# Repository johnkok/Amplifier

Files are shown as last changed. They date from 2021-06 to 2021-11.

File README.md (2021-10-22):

# Amplifier
This is an amplifier project, inluding both software sources for CPU/DSP and also hardware design files.

# folders
**fw:** includes the ST32F407 CPU firmware<br />
**DSP:** includes the ADAU1497 design files<br />
**amp_board:** includes the kicad design foles for the audio power amplifier board<br />
**cntrl_board:** includes the controller board kicad design files<br />
**3d:** 3d printer freecad files<br />

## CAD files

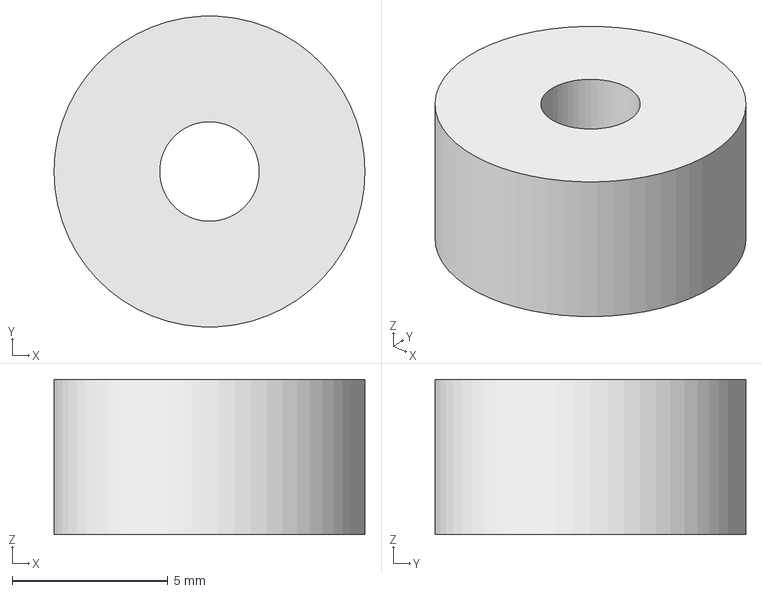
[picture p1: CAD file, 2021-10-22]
3d/spacer.FCStd
10.0 x 9.99 x 5.00 mm

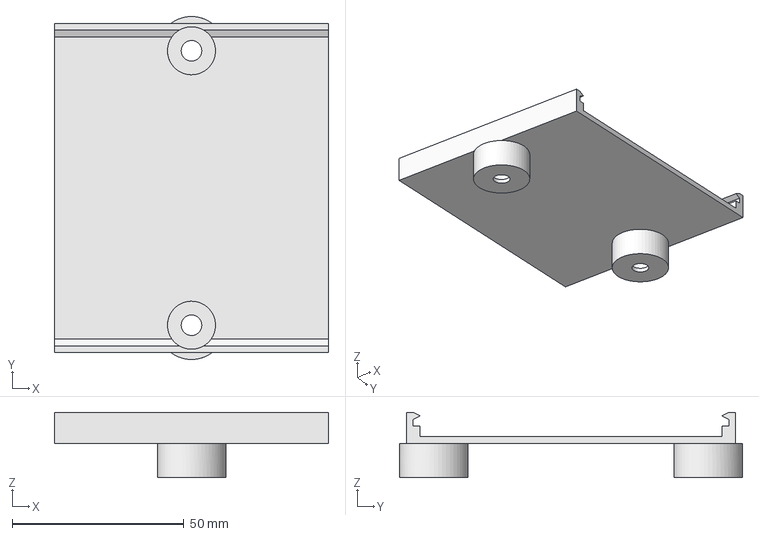
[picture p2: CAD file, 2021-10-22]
3d/holder.FCStd
80.0 x 100.0 x 19.0 mm

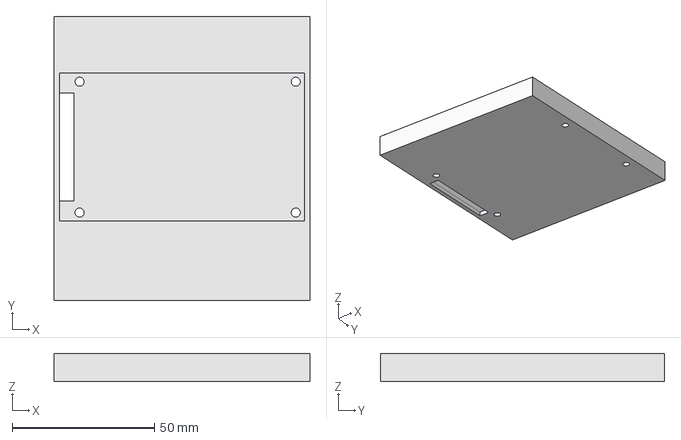
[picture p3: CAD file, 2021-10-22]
3d/lcd_frame.FCStd
90.0 x 100.0 x 10.0 mm

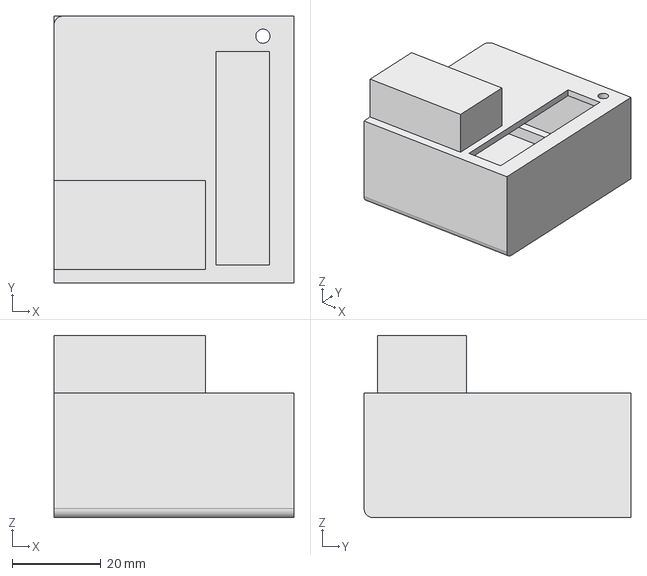
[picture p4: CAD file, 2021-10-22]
3d/fuse.FCStd
54.0 x 60.0 x 41.0 mm

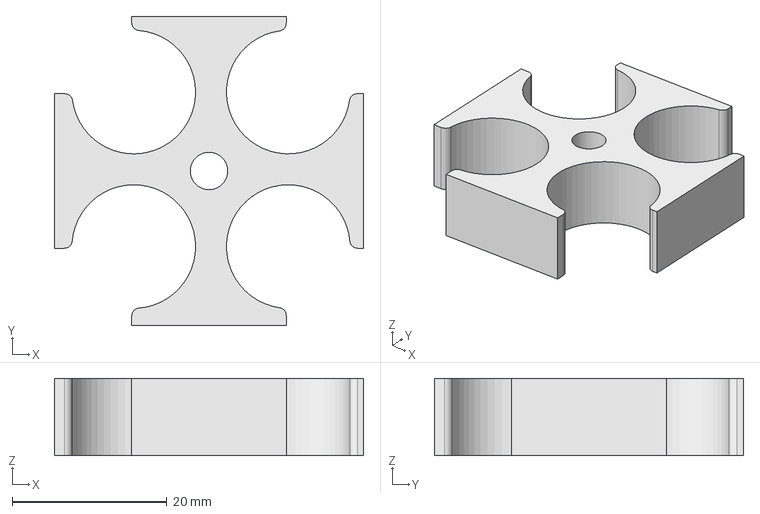
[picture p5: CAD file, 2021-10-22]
3d/cable_spacer.FCStd
40.0 x 40.0 x 10.0 mm

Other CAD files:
3d/cable_spacer.stl
3d/fuse.stl
3d/holder.stl
3d/lcd_frame.stl
3d/spacer.stl

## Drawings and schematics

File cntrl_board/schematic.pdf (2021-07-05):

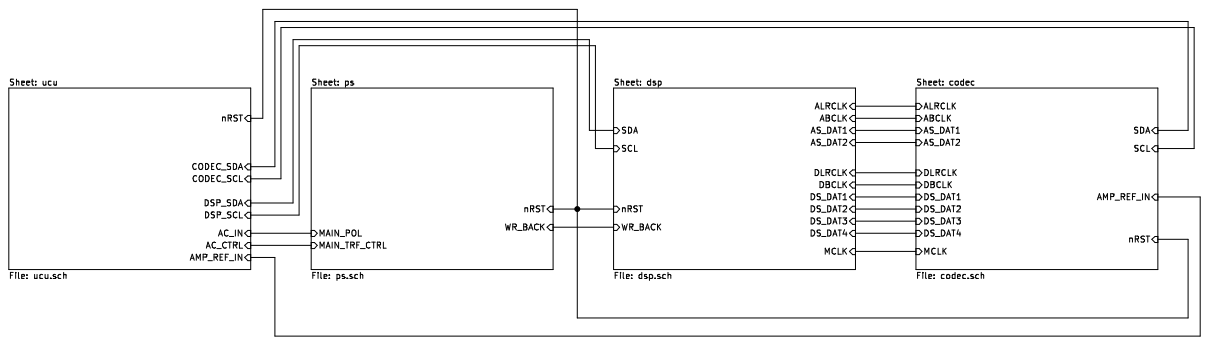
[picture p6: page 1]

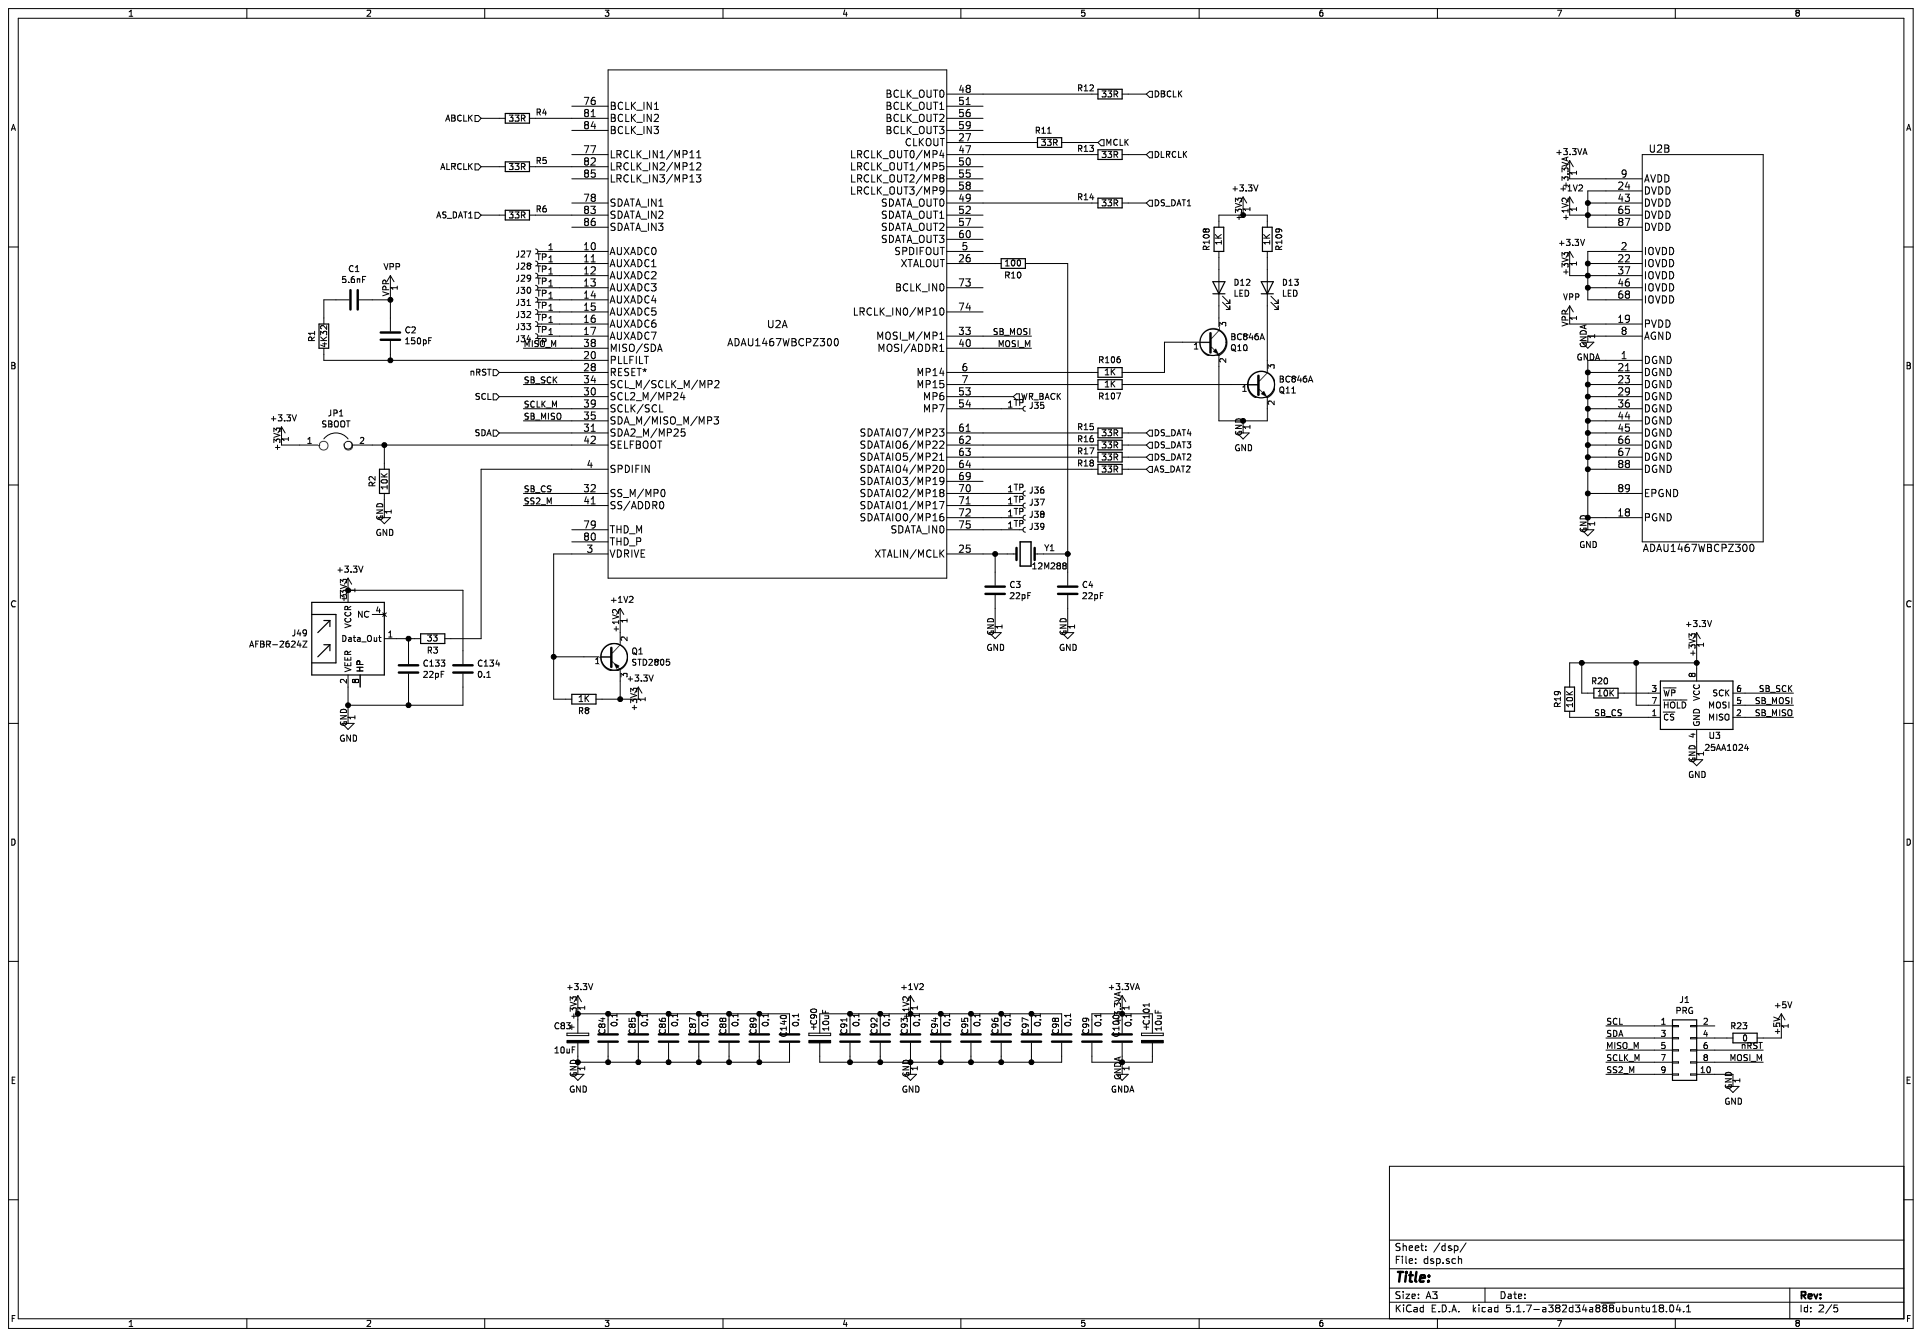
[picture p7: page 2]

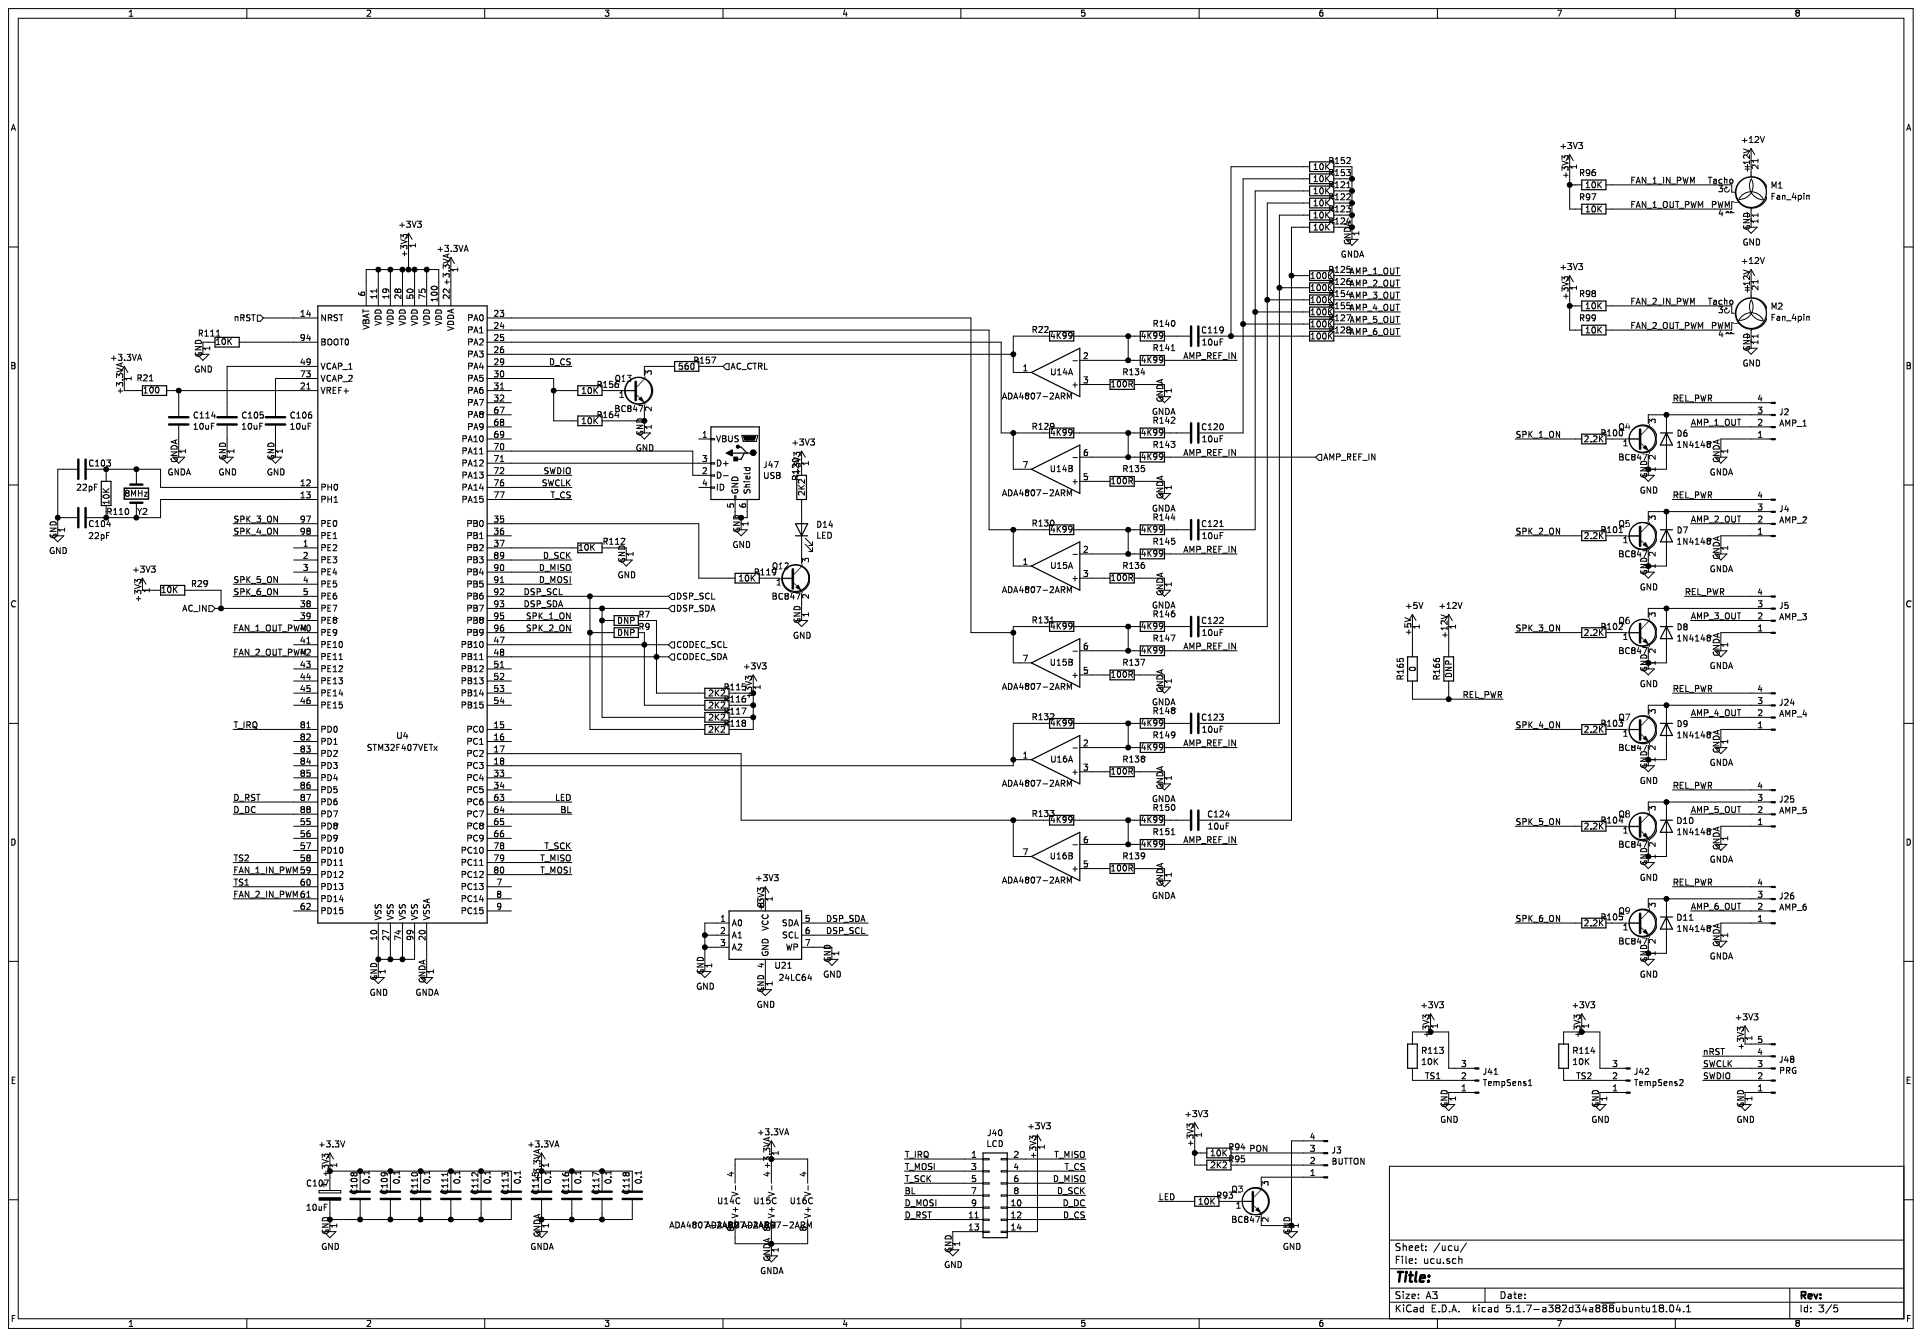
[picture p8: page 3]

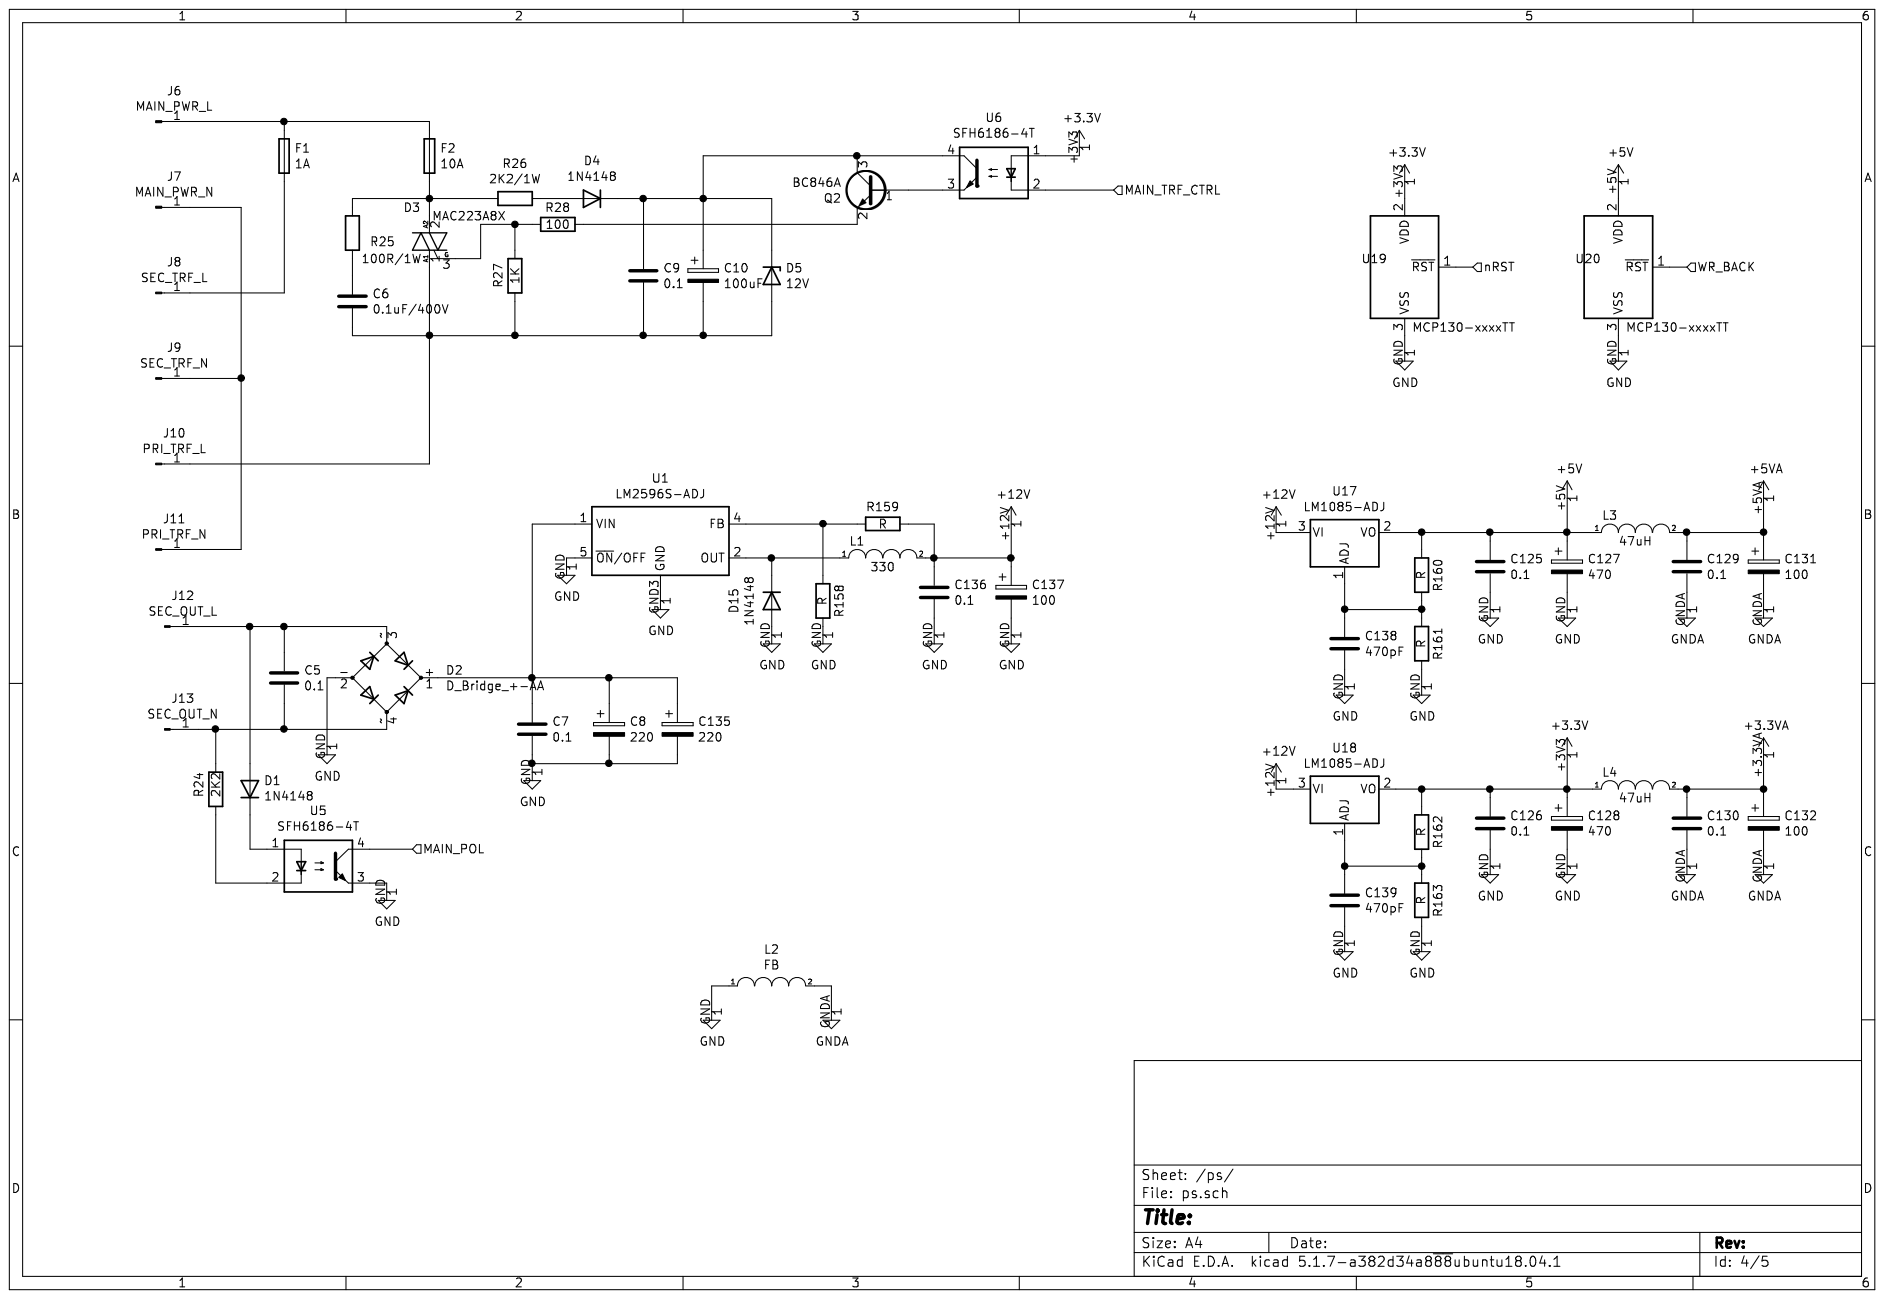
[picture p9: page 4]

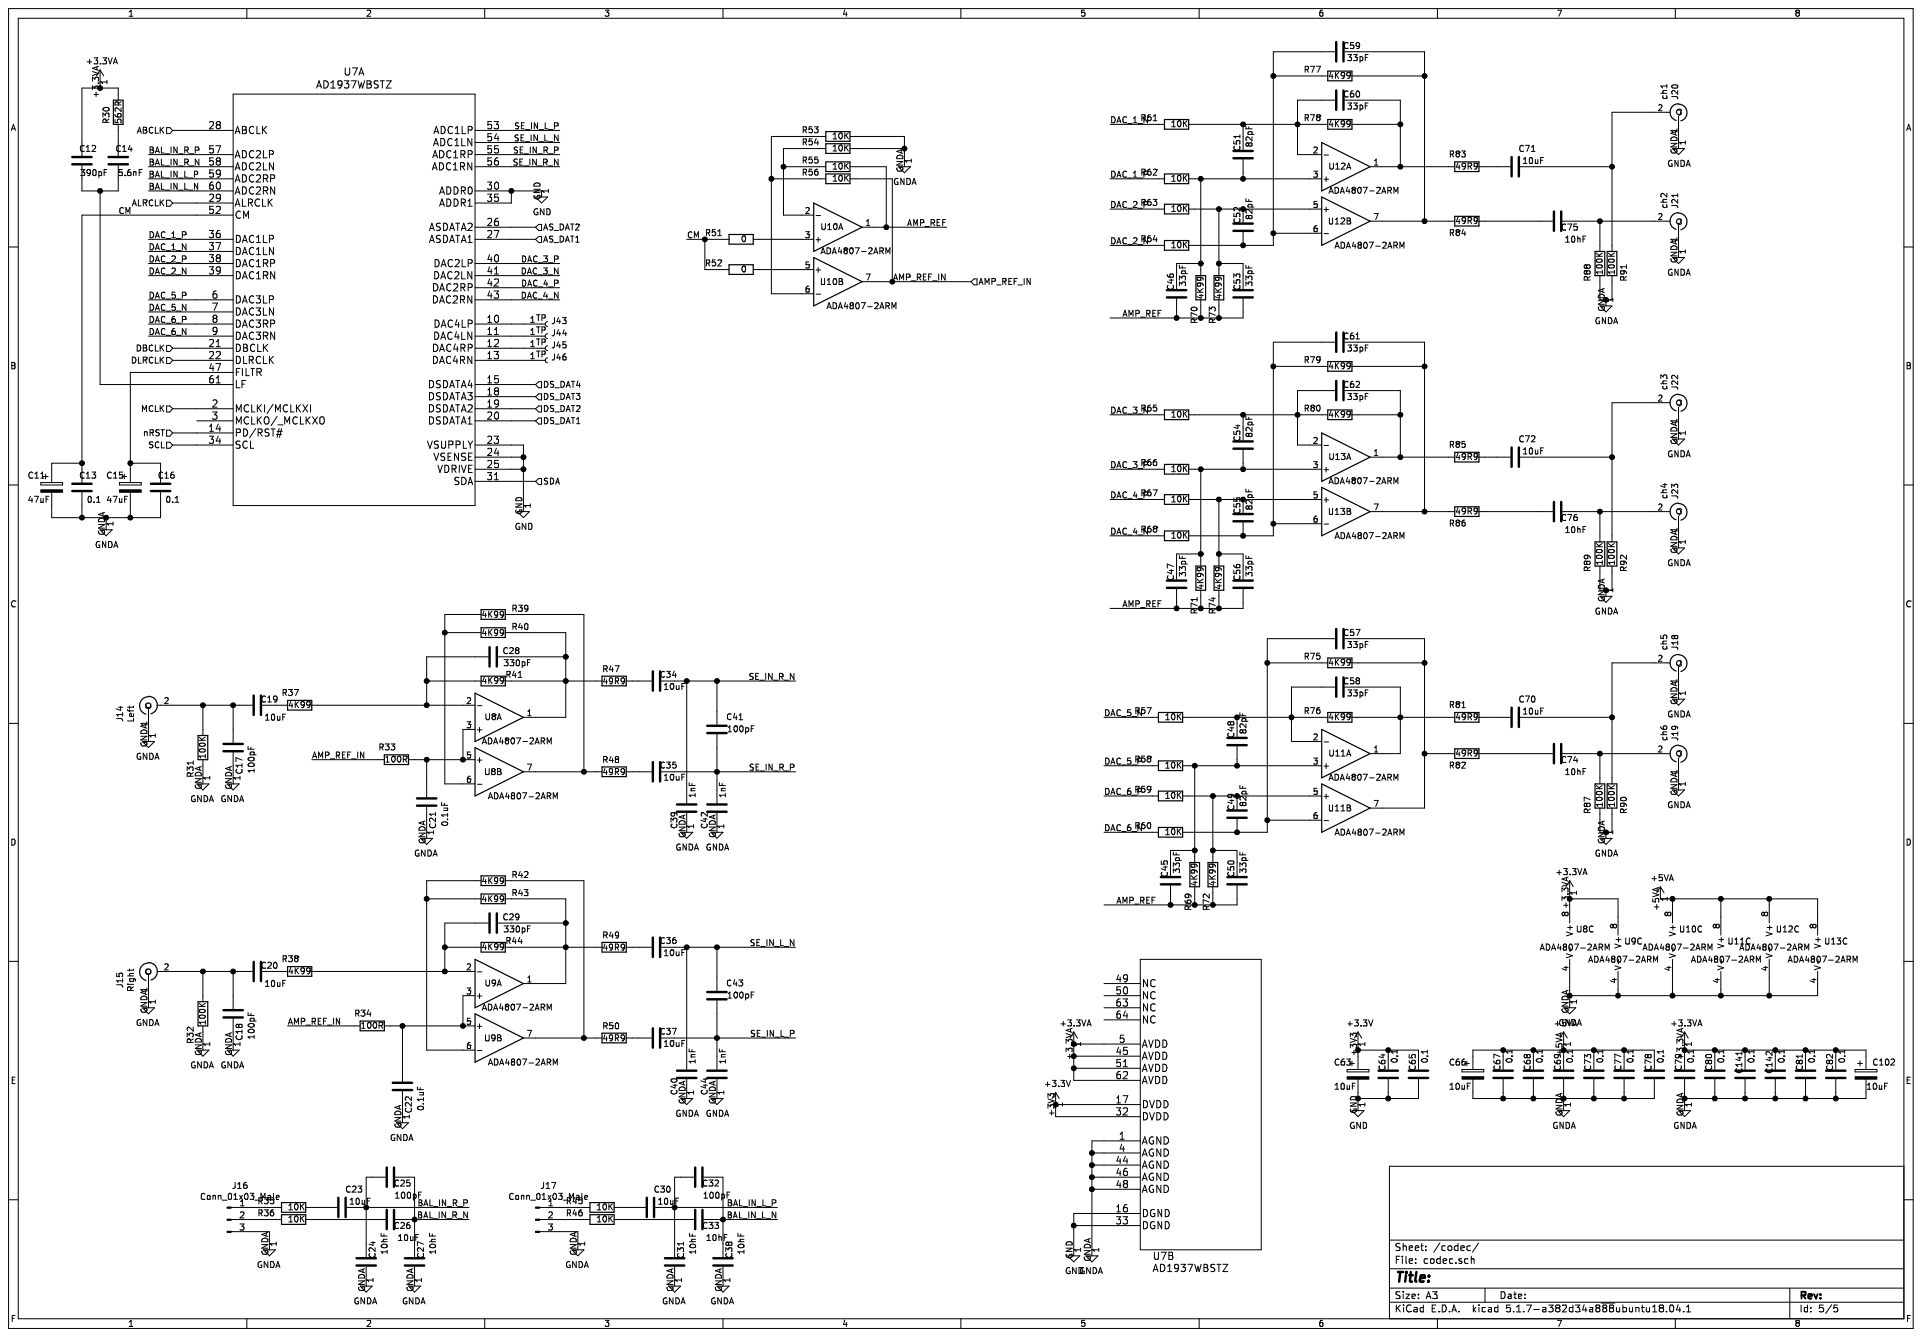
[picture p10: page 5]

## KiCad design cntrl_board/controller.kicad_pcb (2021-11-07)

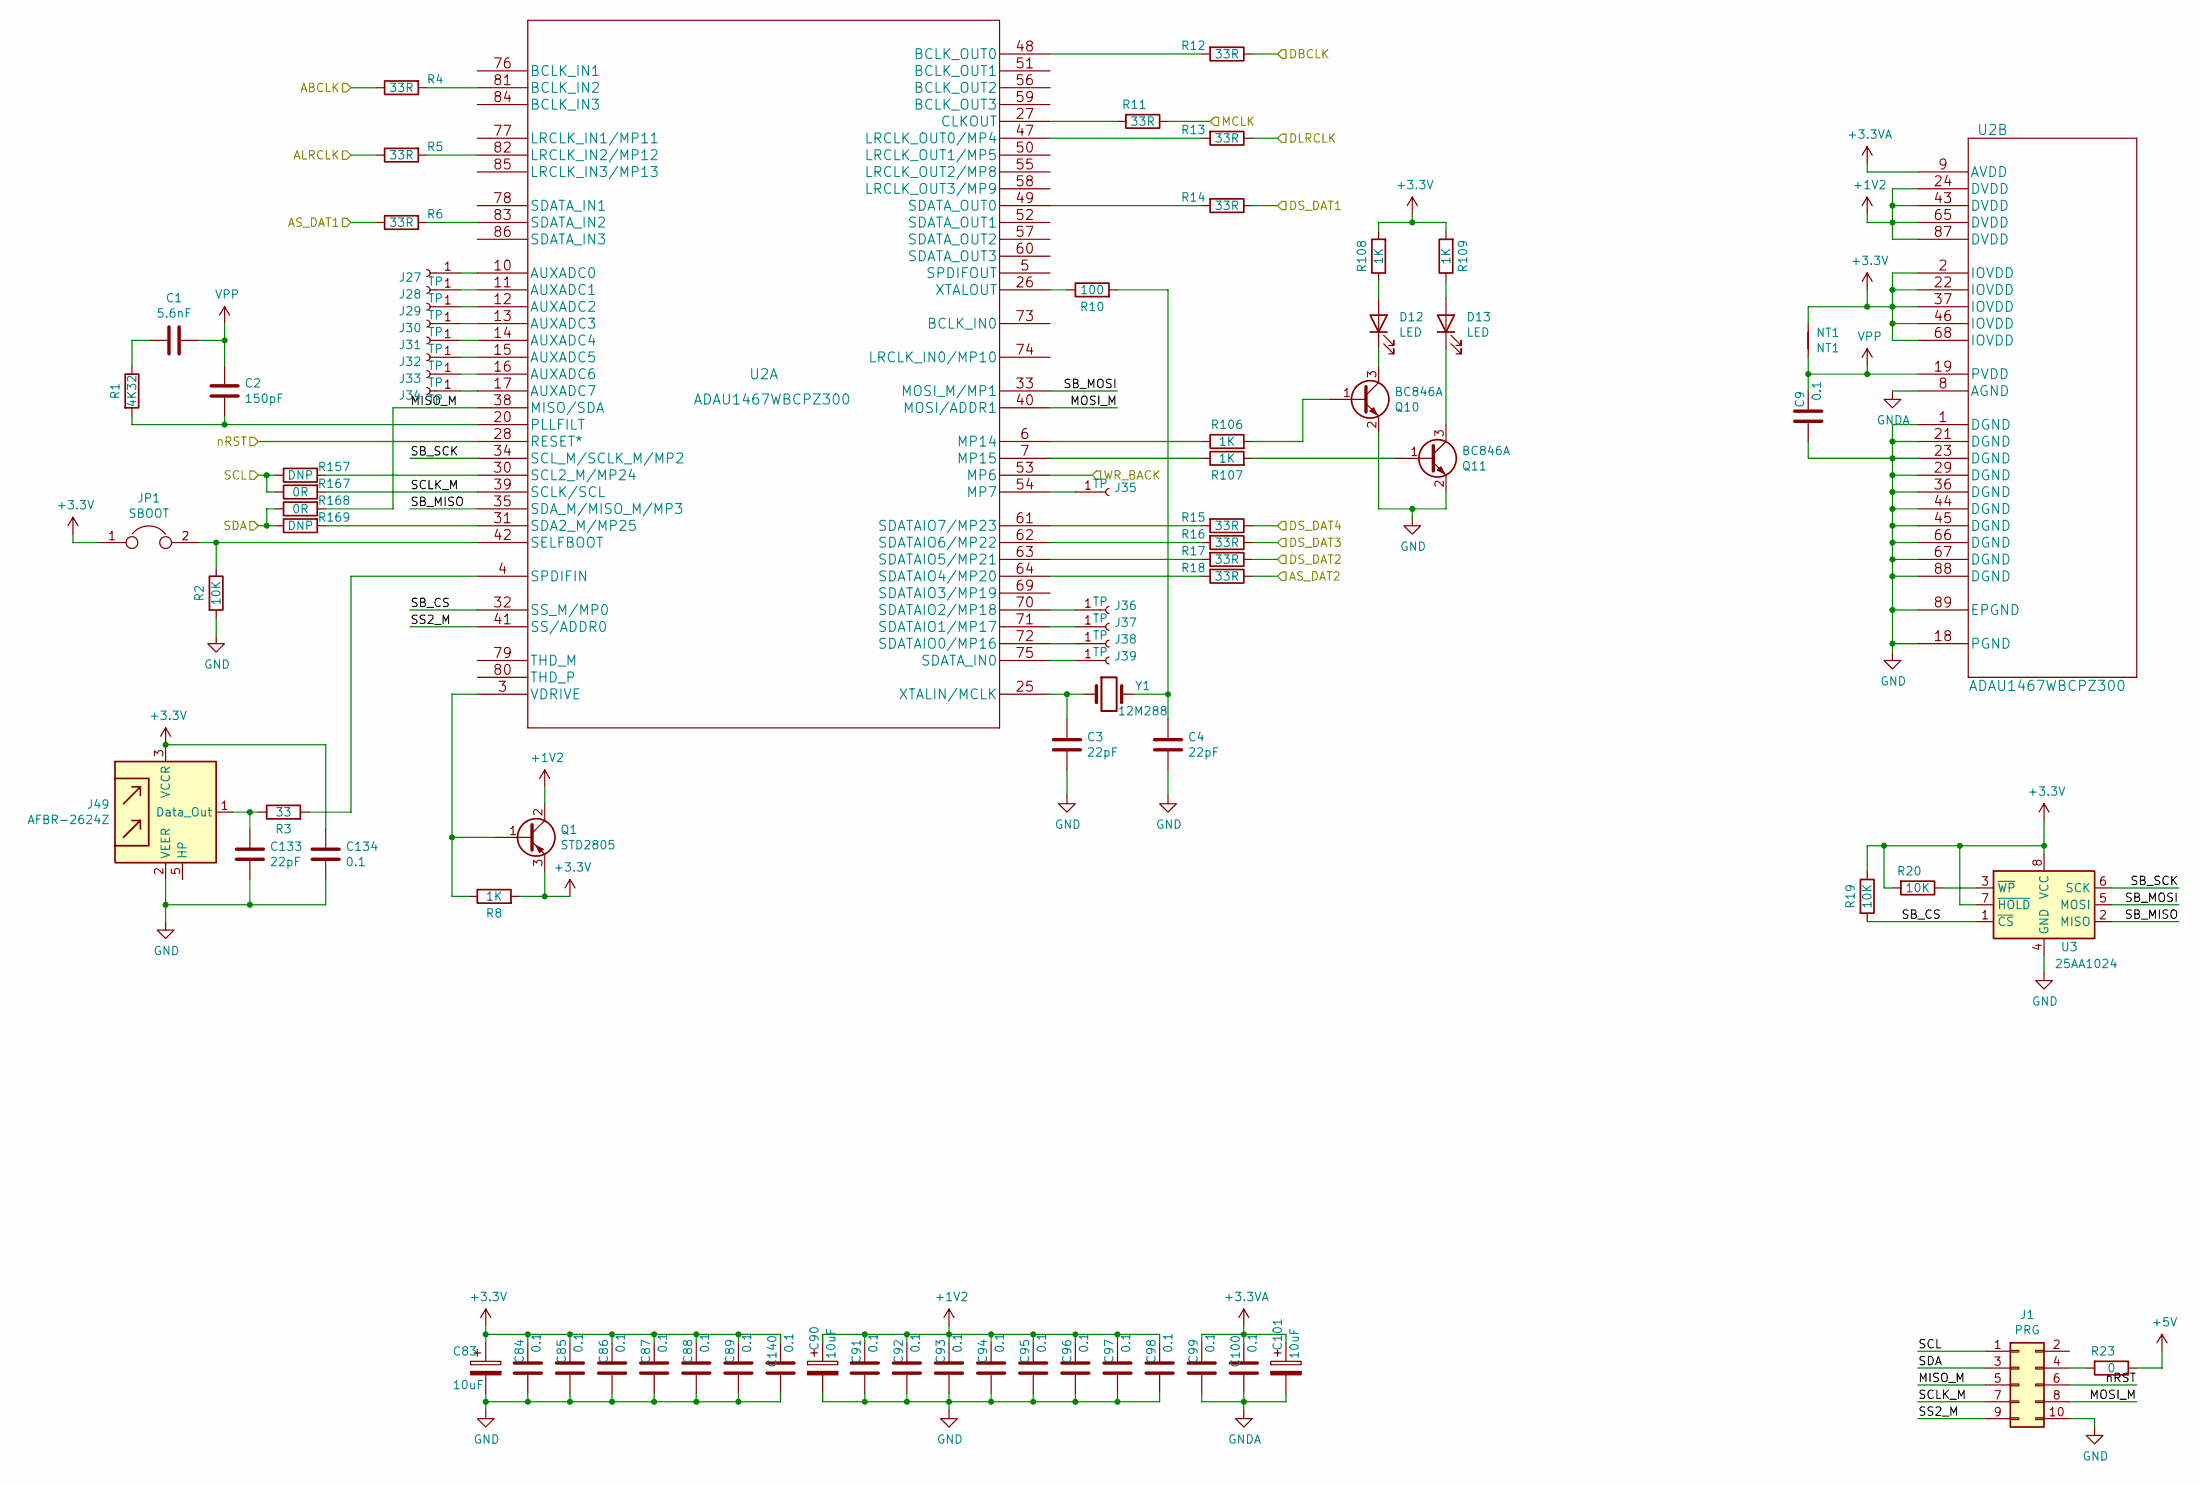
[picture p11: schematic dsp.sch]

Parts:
C1: 5.6nF; C_0603_1608Metric_Pad1.08x0.95mm_HandSolder
C2: 150pF; C_0603_1608Metric_Pad1.08x0.95mm_HandSolder
C3, C4, C133: 22pF; C_0603_1608Metric_Pad1.08x0.95mm_HandSolder
C9, C84, C85, C86, C87, C88, C89, C91, C92, C93, C94, C95, C96, C97, C98, C99, C100, C134, C140: 0.1; C_0603_1608Metric_Pad1.08x0.95mm_HandSolder
C83, C90, C101: 10uF; CP_Elec_5x5.8
D12, D13: LED; LED_0603_1608Metric_Pad1.05x0.95mm_HandSolder
J1: PRG; IDC-Header_2x05_P2.54mm_Vertical
J27, J28, J29, J30, J31, J32, J33, J34, J35, J36, J37, J38, J39: TP; TestPoint_Keystone_5000-5004_Miniature
J49: AFBR-2624Z; TOSLINK
JP1: SBOOT; PinHeader_1x02_P2.54mm_Vertical
NT1: NT1; NetTie-2_SMD_Pad0.5mm
Q1: STD2805; TO-252-3_TabPin2
Q10, Q11: BC846A; SOT-23
R1: 4K32; R_0603_1608Metric_Pad0.98x0.95mm_HandSolder
R2, R19, R20: 10K; R_0603_1608Metric_Pad0.98x0.95mm_HandSolder
R3: 33; R_0603_1608Metric_Pad0.98x0.95mm_HandSolder
R4, R5, R6, R11, R12, R13, R14, R15, R16, R17, R18: 33R; R_0603_1608Metric_Pad0.98x0.95mm_HandSolder
R8, R106, R107, R108, R109: 1K; R_0603_1608Metric_Pad0.98x0.95mm_HandSolder
R10: 100; R_0603_1608Metric_Pad0.98x0.95mm_HandSolder
R23: 0; R_0603_1608Metric_Pad0.98x0.95mm_HandSolder
R157, R169: DNP; R_0603_1608Metric_Pad0.98x0.95mm_HandSolder
R167, R168: 0R; R_0603_1608Metric_Pad0.98x0.95mm_HandSolder
U2: ADAU1467WBCPZ300
U3: 25AA1024; SOIJ-8_5.3x5.3mm_P1.27mm
Y1: 12M288; Crystal_HC49-U_Vertical

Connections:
+1V2: C90.1, C91.1, C92.1, C93.1, C94.1, C95.1, C96.1, C97.1, C98.1, Q1.2 (C), U2.24 (DVDD), U2.43 (DVDD), U2.65 (DVDD), U2.87 (DVDD)
+3.3VA: C99.1, C100.1, C101.1, U2.9 (AVDD); also elsewhere on the board
+5V: R23.1; also elsewhere on the board
/codec/ABCLK: R4.1; also elsewhere on the board
/codec/ALRCLK: R5.1; also elsewhere on the board
/codec/AS_DAT1: R6.1; also elsewhere on the board
/codec/AS_DAT2: R18.1; also elsewhere on the board
/codec/DBCLK: R12.1; also elsewhere on the board
/codec/DLRCLK: R13.1; also elsewhere on the board
/codec/DS_DAT1: R14.1; also elsewhere on the board
/codec/DS_DAT2: R17.1; also elsewhere on the board
/codec/DS_DAT3: R16.1; also elsewhere on the board
/codec/DS_DAT4: R15.1; also elsewhere on the board
/codec/MCLK: R11.1; also elsewhere on the board
/codec/nRST: J1.6, U2.28 (RESET*); also elsewhere on the board
/dsp/MISO_M: J1.5, R168.2, U2.38 (MISO/SDA)
/dsp/MOSI_M: J1.8, U2.40 (MOSI/ADDR1)
/dsp/SB_CS: R19.2, U2.32 (SS_M/MP0), U3.1 (~CS)
/dsp/SB_MISO: U2.35 (SDA_M/MISO_M/MP3), U3.2 (MISO)
/dsp/SB_MOSI: U2.33 (MOSI_M/MP1), U3.5 (MOSI)
/dsp/SB_SCK: U2.34 (SCL_M/SCLK_M/MP2), U3.6 (SCK)
/dsp/SCLK_M: J1.7, R167.2, U2.39 (SCLK/SCL)
/dsp/SS2_M: J1.9, U2.41 (SS/ADDR0)
/dsp/WR_BACK: U2.53 (MP6); also elsewhere on the board
/ucu/DSP_SCL: J1.1, R157.1, R167.1; also elsewhere on the board
/ucu/DSP_SDA: J1.3, R168.1, R169.1; also elsewhere on the board
GND: C3.2, C4.2, C9.2, C83.2, C84.2, C85.2, C86.2, C87.2, C88.2, C89.2, C90.2, C91.2, C92.2, C93.2, C94.2, C95.2, C96.2, C97.2, C98.2, C133.2, C134.2, C140.2, J1.10, J49.2 (VEER), Q10.2 (E), Q11.2 (E), R2.2, U2.1 (DGND), U2.18 (PGND), U2.21 (DGND), U2.23 (DGND), U2.29 (DGND), U2.36 (DGND), U2.44 (DGND), U2.45 (DGND), U2.66 (DGND), U2.67 (DGND), U2.88 (DGND), U2.89 (EPGND), U3.4 (GND); also elsewhere on the board
GNDA: C99.2, C100.2, C101.2, U2.8 (AGND); also elsewhere on the board
unnamed: C1.1, R1.1
unnamed: C2.1, R1.2, U2.20 (PLLFILT)
unnamed: C3.1, U2.25 (XTALIN/MCLK), Y1.1
unnamed: C4.1, R10.2, Y1.2
unnamed: C133.1, J49.1 (Data_Out), R3.1
unnamed: D12.1 (K), Q10.3 (C)
unnamed: D12.2 (A), R108.1
unnamed: D13.1 (K), Q11.3 (C)
unnamed: D13.2 (A), R109.1
unnamed: J1.4, R23.2
unnamed: J27.1, U2.10 (AUXADC0)
unnamed: J28.1, U2.11 (AUXADC1)
unnamed: J29.1, U2.12 (AUXADC2)
unnamed: J30.1, U2.13 (AUXADC3)
unnamed: J31.1, U2.14 (AUXADC4)
unnamed: J32.1, U2.15 (AUXADC5)
unnamed: J33.1, U2.16 (AUXADC6)
unnamed: J34.1, U2.17 (AUXADC7)
unnamed: J35.1, U2.54 (MP7)
unnamed: J36.1, U2.70 (SDATAIO2/MP18)
unnamed: J37.1, U2.71 (SDATAIO1/MP17)
unnamed: J38.1, U2.72 (SDATAIO0/MP16)
unnamed: J39.1, U2.75 (SDATA_IN0)
unnamed: JP1.2, R2.1, U2.42 (SELFBOOT)
unnamed: Q1.1 (B), R8.1, U2.3 (VDRIVE)
unnamed: Q10.1 (B), R106.2
unnamed: Q11.1 (B), R107.2
unnamed: R3.2, U2.4 (SPDIFIN)
unnamed: R4.2, U2.81 (BCLK_IN2)
unnamed: R5.2, U2.82 (LRCLK_IN2/MP12)
unnamed: R6.2, U2.83 (SDATA_IN2)
unnamed: R10.1, U2.26 (XTALOUT)
unnamed: R11.2, U2.27 (CLKOUT)
unnamed: R12.2, U2.48 (BCLK_OUT0)
unnamed: R13.2, U2.47 (LRCLK_OUT0/MP4)
unnamed: R14.2, U2.49 (SDATA_OUT0)
unnamed: R15.2, U2.61 (SDATAIO7/MP23)
unnamed: R16.2, U2.62 (SDATAIO6/MP22)
unnamed: R17.2, U2.63 (SDATAIO5/MP21)
unnamed: R18.2, U2.64 (SDATAIO4/MP20)
unnamed: R20.1, U3.3 (~WP)
unnamed: R106.1, U2.6 (MP14)
unnamed: R107.1, U2.7 (MP15)
unnamed: R157.2, U2.30 (SCL2_M/MP24)
unnamed: R169.2, U2.31 (SDA2_M/MP25)
VPP: C1.2, C2.2, C9.1, NT1.1, U2.19 (PVDD)

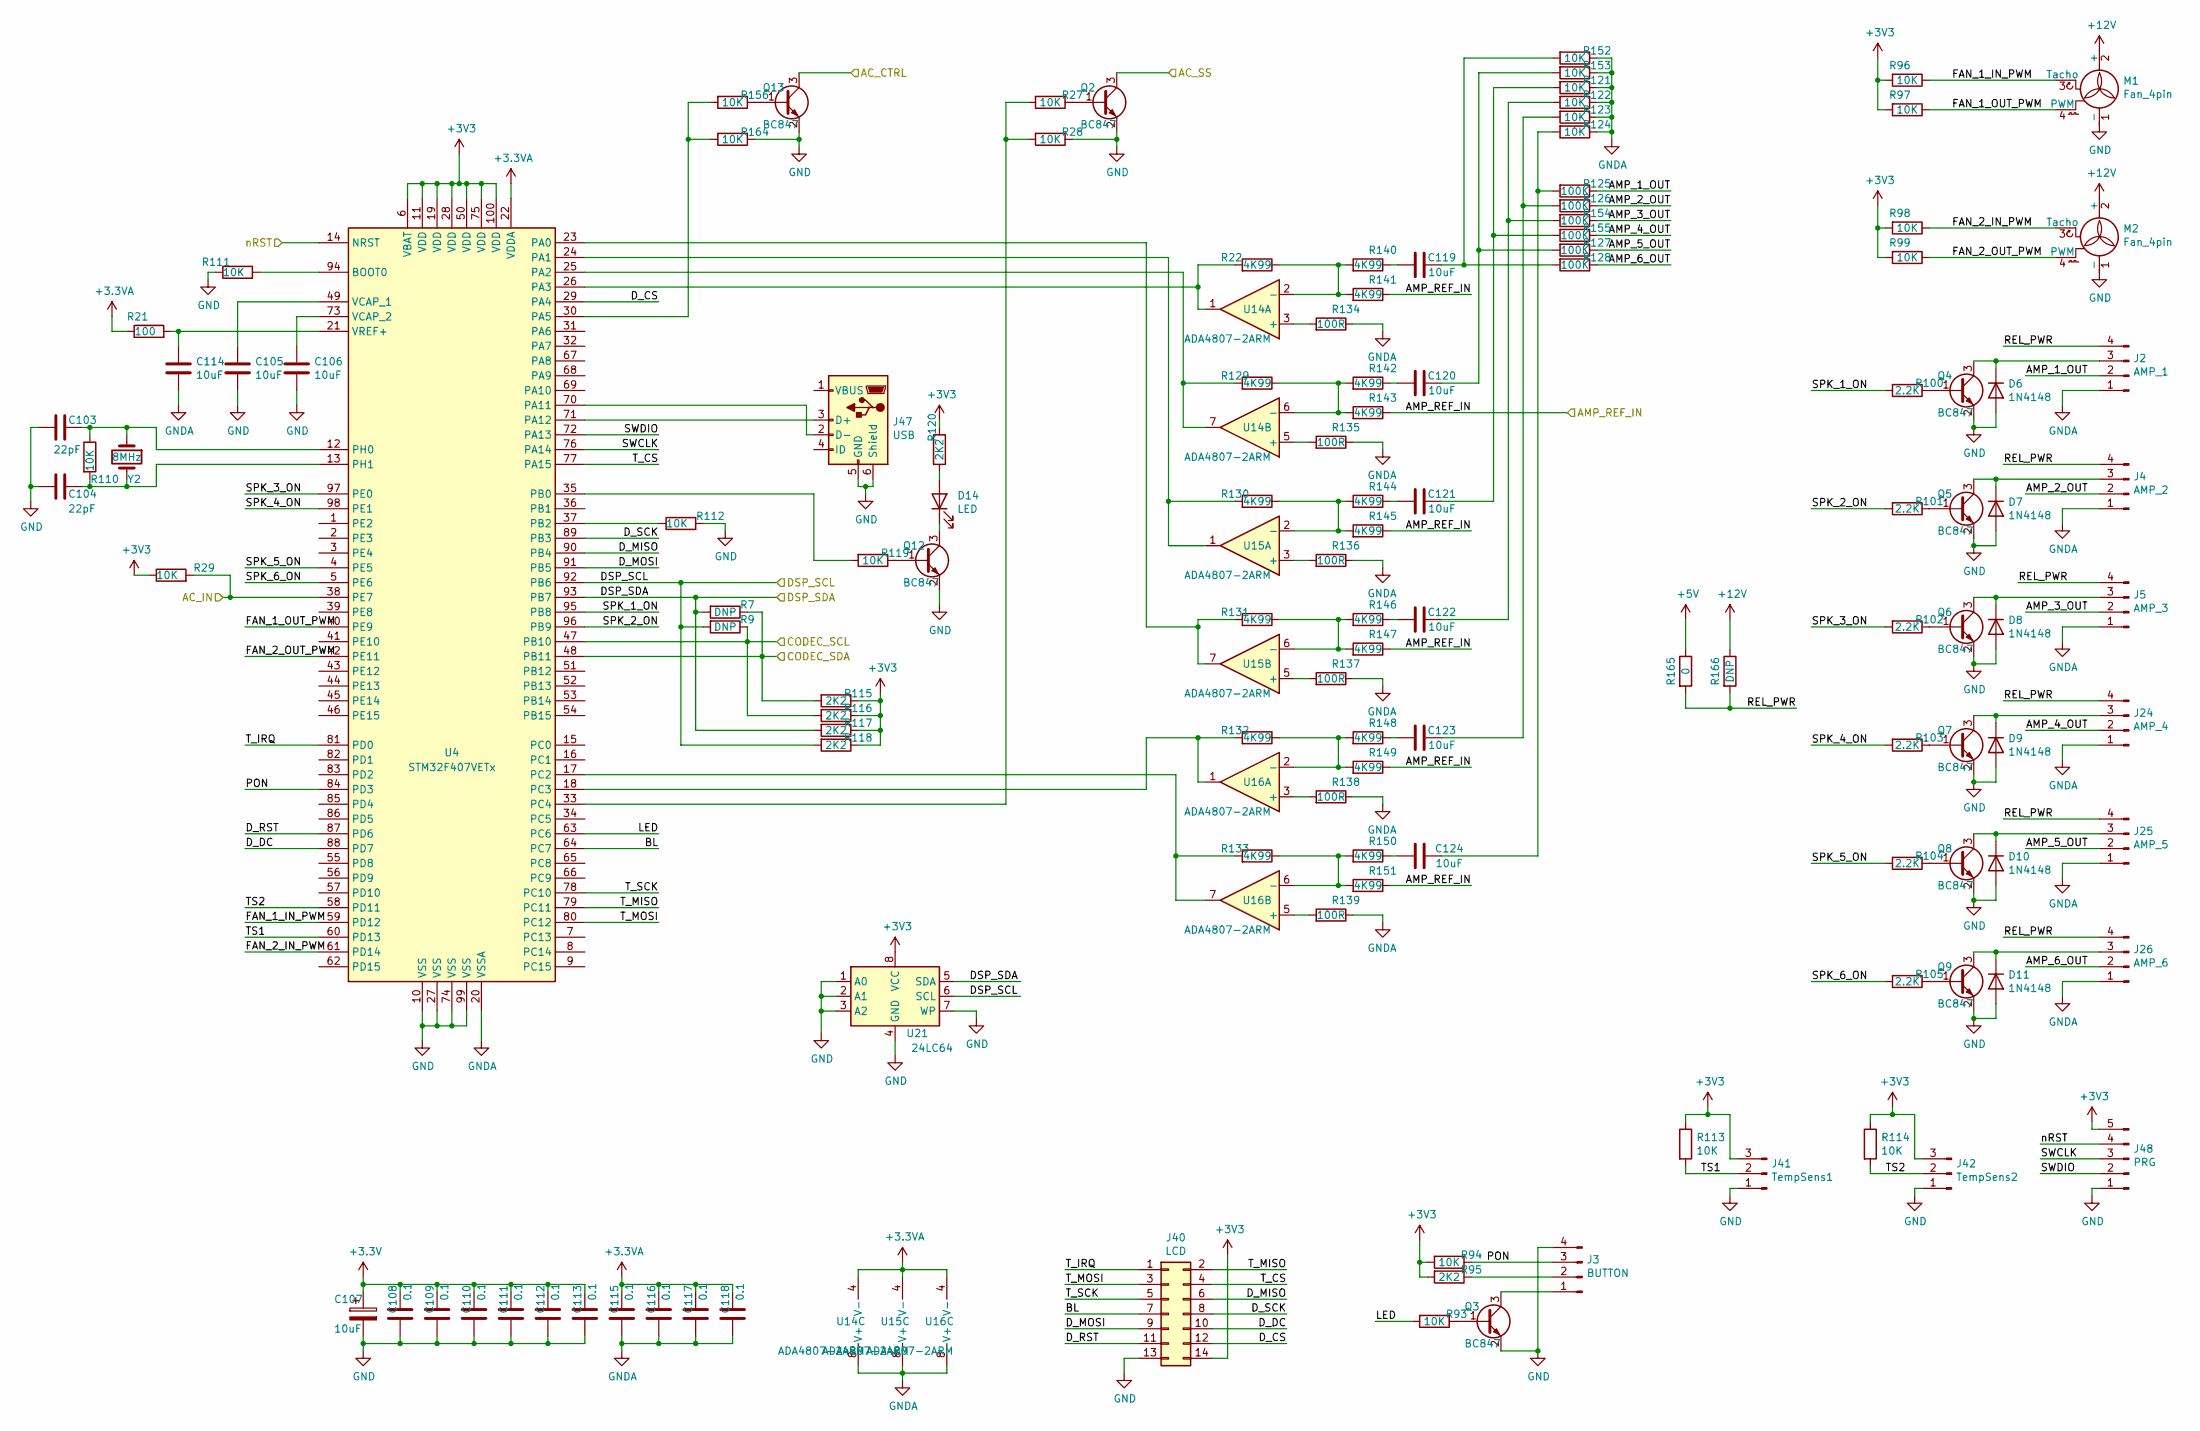
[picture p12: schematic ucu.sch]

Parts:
C103, C104: 22pF; R_0603_1608Metric_Pad0.98x0.95mm_HandSolder
C105, C106, C114, C119, C120, C121, C122, C123, C124: 10uF; C_0805_2012Metric_Pad1.18x1.45mm_HandSolder
C107: 10uF; CP_Elec_5x5.8
C108, C109, C110, C111, C112, C113, C115, C116, C117, C118: 0.1; C_0603_1608Metric_Pad1.08x0.95mm_HandSolder
D6, D7, D8, D9, D10, D11: 1N4148; D_SOD-323_HandSoldering
D14: LED; LED_0603_1608Metric_Pad1.05x0.95mm_HandSolder
J2: AMP_1; PinHeader_1x04_P1.27mm_Vertical
J3: BUTTON; PinHeader_1x04_P2.54mm_Vertical
J4: AMP_2; PinHeader_1x04_P1.27mm_Vertical
J5: AMP_3; PinHeader_1x04_P1.27mm_Vertical
J24: AMP_4; PinHeader_1x04_P1.27mm_Vertical
J25: AMP_5; PinHeader_1x04_P1.27mm_Vertical
J26: AMP_6; PinHeader_1x04_P1.27mm_Vertical
J40: LCD; PinSocket_2x07_P2.54mm_Vertical
J41: TempSens1; PinHeader_1x03_P2.54mm_Vertical
J42: TempSens2; PinHeader_1x03_P2.54mm_Vertical
J47: USB; USB_Micro-B_Molex-105017-0001
J48: PRG; PinSocket_1x05_P2.54mm_Vertical
M1, M2: Fan_4pin; PinHeader_1x04_P2.54mm_Vertical
Q2, Q3, Q4, Q5, Q6, Q7, Q8, Q9, Q12, Q13: BC847; SOT-23
R7, R9: DNP; R_0603_1608Metric_Pad0.98x0.95mm_HandSolder
R21: 100; R_0603_1608Metric_Pad0.98x0.95mm_HandSolder
R22, R129, R130, R131, R132, R133, R140, R141, R142, R143, R144, R145, R146, R147, R148, R149, R150, R151: 4K99; R_0603_1608Metric_Pad0.98x0.95mm_HandSolder
R27, R28, R29, R93, R94, R96, R97, R98, R99, R110, R111, R112, R113, R114, R119, R121, R122, R123, R124, R152, R153, R156, R164: 10K; R_0603_1608Metric_Pad0.98x0.95mm_HandSolder
R95, R115, R116, R117, R118, R120: 2K2; R_0603_1608Metric_Pad0.98x0.95mm_HandSolder
R100, R101, R102, R103, R104, R105: 2.2K; R_0603_1608Metric_Pad0.98x0.95mm_HandSolder
R125, R126, R127, R128, R154, R155: 100K; R_0603_1608Metric_Pad0.98x0.95mm_HandSolder
R134, R135, R136, R137, R138, R139: 100R; R_0603_1608Metric_Pad0.98x0.95mm_HandSolder
R165: 0; R_1206_3216Metric_Pad1.30x1.75mm_HandSolder
R166: DNP; R_1206_3216Metric_Pad1.30x1.75mm_HandSolder
U4: STM32F407VETx; LQFP-100_14x14mm_P0.5mm
U14, U15, U16: ADA4807-2ARM; MSOP-8_3x3mm_P0.65mm
U21: 24LC64; SO-8_3.9x4.9mm_P1.27mm
Y2: 8MHz; Crystal_HC49-4H_Vertical

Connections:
+3.3VA: C115.1, C116.1, C117.1, C118.1, R21.1, U4.22 (VDDA), U14.4 (V-), U15.4 (V-), U16.4 (V-); also elsewhere on the board
+5V: R165.1; also elsewhere on the board
+12V: M1.2 (+), M2.2 (+), R166.1; also elsewhere on the board
/codec/AMP_REF_IN: R141.1, R143.1, R145.1, R147.1, R149.1, R151.1; also elsewhere on the board
/codec/nRST: J48.4, U4.14 (NRST); also elsewhere on the board
/ucu/AC_CTRL: Q13.3 (C); also elsewhere on the board
/ucu/AC_IN: R29.2, U4.38 (PE7); also elsewhere on the board
/ucu/AC_SS: Q2.3 (C); also elsewhere on the board
/ucu/AMP_1_OUT: J2.2, R125.1
/ucu/AMP_2_OUT: J4.2, R126.1
/ucu/AMP_3_OUT: J5.2, R154.1
/ucu/AMP_4_OUT: J24.2, R155.1
/ucu/AMP_5_OUT: J25.2, R127.1
/ucu/AMP_6_OUT: J26.2, R128.1
/ucu/BL: J40.7, U4.64 (PC7)
/ucu/CODEC_SCL: R9.1, R116.2, U4.47 (PB10); also elsewhere on the board
/ucu/CODEC_SDA: R7.1, R115.2, U4.48 (PB11); also elsewhere on the board
/ucu/DSP_SCL: R9.2, R118.2, U4.92 (PB6), U21.6 (SCL); also elsewhere on the board
/ucu/DSP_SDA: R7.2, R117.2, U4.93 (PB7), U21.5 (SDA); also elsewhere on the board
/ucu/D_CS: J40.12, U4.29 (PA4)
/ucu/D_DC: J40.10, U4.88 (PD7)
/ucu/D_MISO: J40.6, U4.90 (PB4)
/ucu/D_MOSI: J40.9, U4.91 (PB5)
/ucu/D_RST: J40.11, U4.87 (PD6)
/ucu/D_SCK: J40.8, U4.89 (PB3)
/ucu/FAN_1_IN_PWM: M1.3 (Tacho), R96.1, U4.59 (PD12)
/ucu/FAN_1_OUT_PWM: M1.4 (PWM), R97.1, U4.40 (PE9)
/ucu/FAN_2_IN_PWM: M2.3 (Tacho), R98.1, U4.61 (PD14)
/ucu/FAN_2_OUT_PWM: M2.4 (PWM), R99.1, U4.42 (PE11)
/ucu/LED: R93.2, U4.63 (PC6)
/ucu/PON: J3.3, R94.1, U4.84 (PD3)
/ucu/REL_PWR: J2.4, J4.4, J5.4, J24.4, J25.4, J26.4, R165.2, R166.2
/ucu/SPK_1_ON: R100.2, U4.95 (PB8)
/ucu/SPK_2_ON: R101.2, U4.96 (PB9)
/ucu/SPK_3_ON: R102.2, U4.97 (PE0)
/ucu/SPK_4_ON: R103.2, U4.98 (PE1)
/ucu/SPK_5_ON: R104.2, U4.4 (PE5)
/ucu/SPK_6_ON: R105.2, U4.5 (PE6)
/ucu/SWCLK: J48.3, U4.76 (PA14)
/ucu/SWDIO: J48.2, U4.72 (PA13)
/ucu/TS1: J41.2, R113.2, U4.60 (PD13)
/ucu/TS2: J42.2, R114.2, U4.58 (PD11)
/ucu/T_CS: J40.4, U4.77 (PA15)
/ucu/T_IRQ: J40.1, U4.81 (PD0)
/ucu/T_MISO: J40.2, U4.79 (PC11)
/ucu/T_MOSI: J40.3, U4.80 (PC12)
/ucu/T_SCK: J40.5, U4.78 (PC10)
GND: C103.2, C104.2, C105.2, C106.2, C107.2, C108.2, C109.2, C110.2, C111.2, C112.2, C113.2, D6.2 (A), D7.2 (A), D8.2 (A), D9.2 (A), D10.2 (A), D11.2 (A), J3.4, J40.13, J41.1, J42.1, J47.5 (GND), J47.6 (Shield), J48.1, M1.1 (-), M2.1 (-), Q2.2 (E), Q3.2 (E), Q4.2 (E), Q5.2 (E), Q6.2 (E), Q7.2 (E), Q8.2 (E), Q9.2 (E), Q12.2 (E), Q13.2 (E), R28.1, R111.1, R112.2, R164.1, U4.10 (VSS), U4.27 (VSS), U4.74 (VSS), U4.99 (VSS), U21.1 (A0), U21.2 (A1), U21.3 (A2), U21.4 (GND), U21.7 (WP); also elsewhere on the board
GNDA: C114.2, C115.2, C116.2, C117.2, C118.2, J2.1, J4.1, J5.1, J24.1, J25.1, J26.1, R121.1, R122.1, R123.1, R124.1, R134.1, R135.1, R136.1, R137.1, R138.1, R139.1, R152.1, R153.1, U4.20 (VSSA), U14.8 (V+), U15.8 (V+), U16.8 (V+); also elsewhere on the board
unnamed: C103.1, R110.1, U4.12 (PH0), Y2.1
unnamed: C104.1, R110.2, U4.13 (PH1), Y2.2
unnamed: C105.1, U4.49 (VCAP_1)
unnamed: C106.1, U4.73 (VCAP_2)
unnamed: C114.1, R21.2, U4.21 (VREF+)
unnamed: C119.1, R140.1
unnamed: C119.2, R128.2, R152.2
unnamed: C120.1, R142.1
unnamed: C120.2, R127.2, R153.2
unnamed: C121.1, R144.1
unnamed: C121.2, R121.2, R155.2
unnamed: C122.1, R146.1
unnamed: C122.2, R122.2, R154.2
unnamed: C123.1, R148.1
unnamed: C123.2, R123.2, R126.2
unnamed: C124.1, R150.1
unnamed: C124.2, R124.2, R125.2
unnamed: D6.1 (K), J2.3, Q4.3 (C)
unnamed: D7.1 (K), J4.3, Q5.3 (C)
unnamed: D8.1 (K), J5.3, Q6.3 (C)
unnamed: D9.1 (K), J24.3, Q7.3 (C)
unnamed: D10.1 (K), J25.3, Q8.3 (C)
unnamed: D11.1 (K), J26.3, Q9.3 (C)
unnamed: D14.1 (K), Q12.3 (C)
unnamed: D14.2 (A), R120.2
unnamed: J3.1, Q3.3 (C)
unnamed: J3.2, R95.1
unnamed: J47.2 (D-), U4.70 (PA11)
unnamed: J47.3 (D+), U4.71 (PA12)
unnamed: Q2.1 (B), R27.1
unnamed: Q3.1 (B), R93.1
unnamed: Q4.1 (B), R100.1
unnamed: Q5.1 (B), R101.1
unnamed: Q6.1 (B), R102.1
unnamed: Q7.1 (B), R103.1
unnamed: Q8.1 (B), R104.1
unnamed: Q9.1 (B), R105.1
unnamed: Q12.1 (B), R119.1
unnamed: Q13.1 (B), R156.1
unnamed: R22.2, U4.26 (PA3), U14.1
unnamed: R27.2, R28.2, U4.33 (PC4)
unnamed: R111.2, U4.94 (BOOT0)
unnamed: R112.1, U4.37 (PB2)
unnamed: R119.2, U4.35 (PB0)
unnamed: R129.1, R142.2, R143.2, U14.6 (-)
unnamed: R129.2, U4.25 (PA2), U14.7
unnamed: R130.1, R144.2, R145.2, U15.2 (-)
unnamed: R130.2, U4.24 (PA1), U15.1
unnamed: R131.1, R146.2, R147.2, U15.6 (-)
unnamed: R131.2, U4.23 (PA0), U15.7
unnamed: R132.1, R148.2, R149.2, U16.2 (-)
unnamed: R132.2, U4.18 (PC3), U16.1
unnamed: R133.1, R150.2, R151.2, U16.6 (-)
unnamed: R133.2, U4.17 (PC2), U16.7
unnamed: R134.2, U14.3 (+)
unnamed: R135.2, U14.5 (+)
unnamed: R136.2, U15.3 (+)
unnamed: R137.2, U15.5 (+)
unnamed: R138.2, U16.3 (+)
unnamed: R139.2, U16.5 (+)
unnamed: R22.1, R140.2, R141.2, U14.2 (-)
unnamed: R156.2, R164.2, U4.30 (PA5)

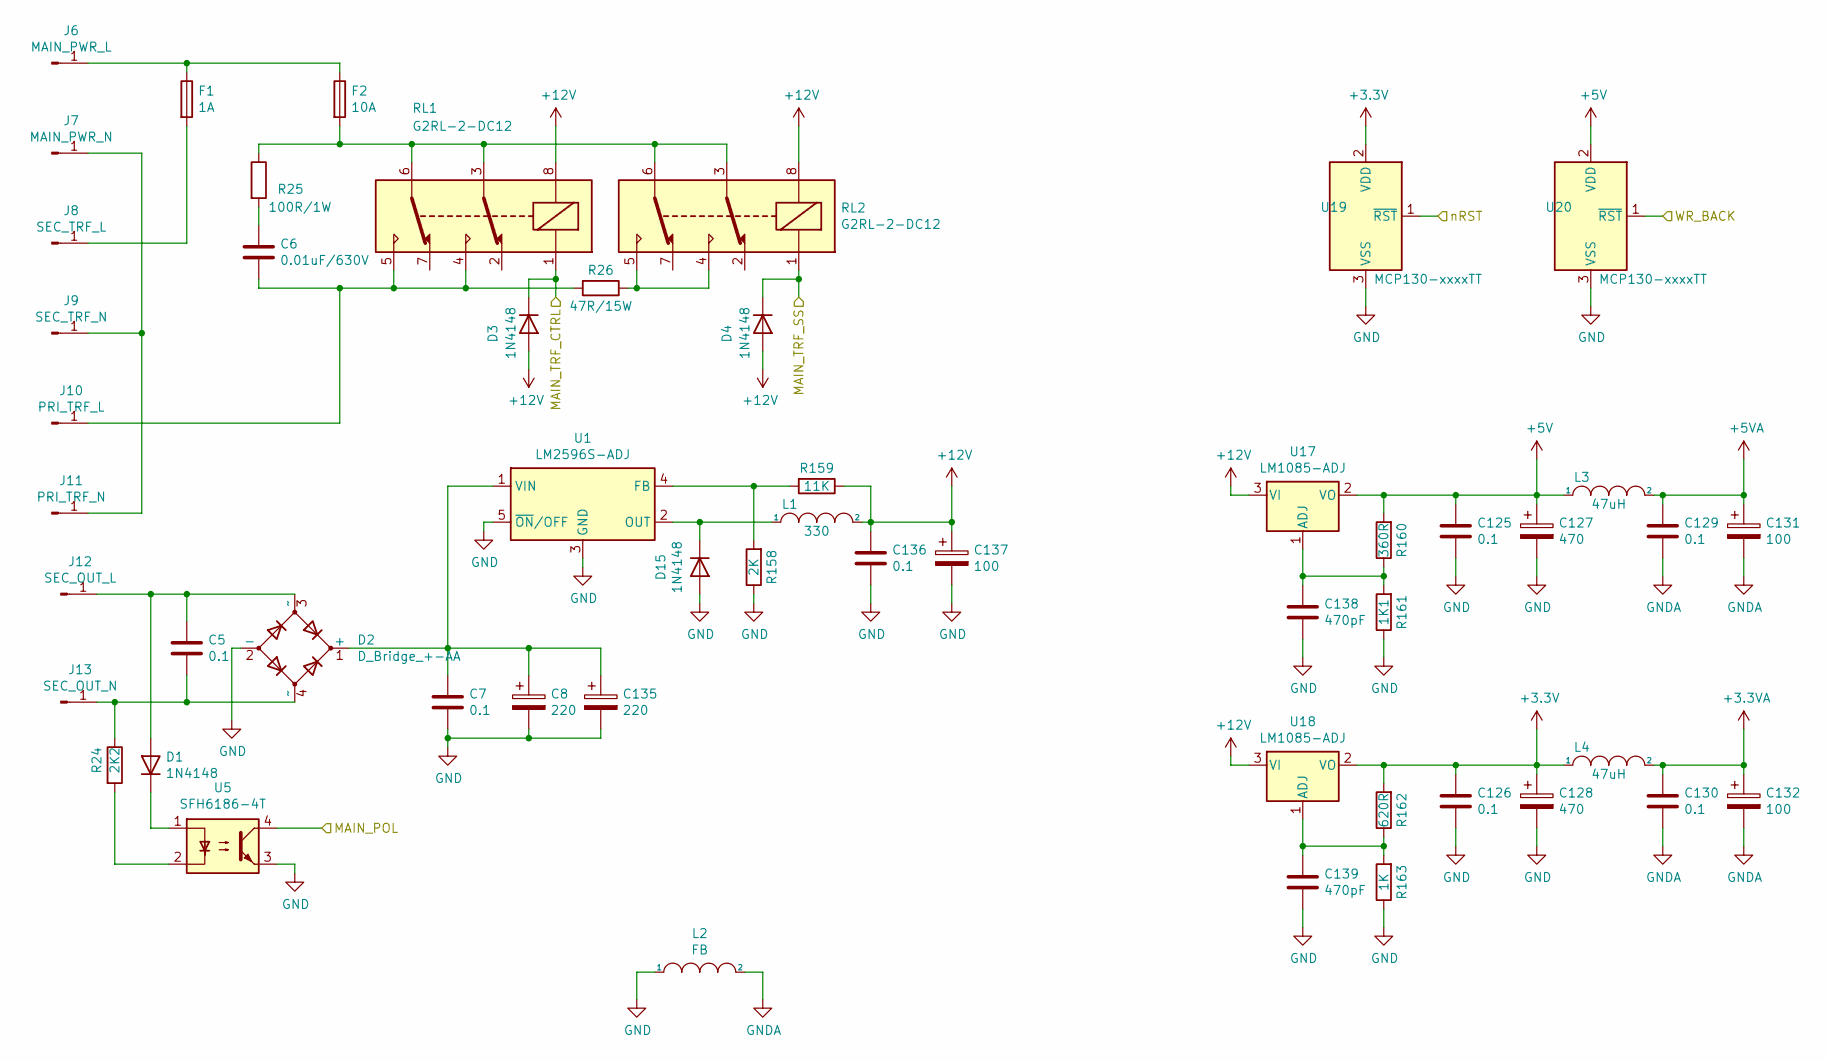
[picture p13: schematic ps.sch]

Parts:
C5, C7, C125, C126, C129, C130, C136: 0.1; C_0603_1608Metric_Pad1.08x0.95mm_HandSolder
C6: 0.01uF/630V; C_Disc_D8.0mm_W5.0mm_P10.00mm
C8, C135: 220; CP_Elec_8x6.2
C127, C128: 470; CP_Elec_8x6.5
C131, C132, C137: 100; CP_Elec_6.3x7.7
C138, C139: 470pF; C_0603_1608Metric_Pad1.08x0.95mm_HandSolder
D1, D3, D4, D15: 1N4148; D_SOD-323_HandSoldering
D2: D_Bridge_+-AA; Diode_Bridge_Vishay_DFS
F1: 1A; Fuseholder_Cylinder-5x20mm_Schurter_0031_8201_Horizontal_Op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
F2: 10A; Fuseholder_Cylinder-5x20mm_Schurter_0031_8201_Horizontal_Op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
J6: MAIN_PWR_L; TERMINAL_250
J7: MAIN_PWR_N; TERMINAL_250
J8: SEC_TRF_L; TERMINAL_250
J9: SEC_TRF_N; TERMINAL_250
J10: PRI_TRF_L; TERMINAL_250
J11: PRI_TRF_N; TERMINAL_250
J12: SEC_OUT_L; TERMINAL_250
J13: SEC_OUT_N; TERMINAL_250
L1: 330; L_12x12mm_H4.5mm
L2: FB; L_0805_2012Metric_Pad1.15x1.40mm_HandSolder
L3, L4: 47uH; L_Bourns-SRU8028_8.0x8.0mm
R24: 2K2; R_0603_1608Metric_Pad0.98x0.95mm_HandSolder
R25: 100R/1W; R_Axial_DIN0414_L11.9mm_D4.5mm_P15.24mm_Horizontal
R26: 47R/15W; R_Radial_Power_L13.0mm_W9.0mm_P5.00mm
R158: 2K; R_0603_1608Metric_Pad0.98x0.95mm_HandSolder
R159: 11K; R_0603_1608Metric_Pad0.98x0.95mm_HandSolder
R160: 360R; R_0603_1608Metric_Pad0.98x0.95mm_HandSolder
R161: 1K1; R_0603_1608Metric_Pad0.98x0.95mm_HandSolder
R162: 620R; R_0603_1608Metric_Pad0.98x0.95mm_HandSolder
R163: 1K; R_0603_1608Metric_Pad0.98x0.95mm_HandSolder
RL1, RL2: G2RL-2-DC12; Relay_DPDT_Omron_G2RL
U1: LM2596S-ADJ; TO-263-5_TabPin3
U5: SFH6186-4T; SO-4_7.6x3.6mm_P2.54mm
U17, U18: LM1085-ADJ; TO-263-3_TabPin2
U19, U20: MCP130-xxxxTT; SOT-23

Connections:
+3.3VA: C130.1, C132.1, L4.2; also elsewhere on the board
+5V: C125.1, C127.1, L3.1, R160.2, U17.2 (VO), U20.2 (VDD); also elsewhere on the board
+5VA: C129.1, C131.1, L3.2; also elsewhere on the board
+12V: C136.1, C137.1, D3.2 (A), D4.2 (A), L1.2, R159.1, RL1.8, RL2.8, U17.3 (VI), U18.3 (VI); also elsewhere on the board
/codec/nRST: U19.1 (~RST); also elsewhere on the board
/dsp/WR_BACK: U20.1 (~RST); also elsewhere on the board
/ucu/AC_CTRL: D3.1 (K), RL1.1; also elsewhere on the board
/ucu/AC_IN: U5.4; also elsewhere on the board
/ucu/AC_SS: D4.1 (K), RL2.1; also elsewhere on the board
GND: C7.2, C8.2, C125.2, C126.2, C127.2, C128.2, C135.2, C136.2, C137.2, C138.2, C139.2, D2.2 (-), D15.2 (A), L2.1, R158.1, R161.1, R163.1, U1.3 (GND), U1.5 (~ON~/OFF), U5.3, U19.3 (VSS), U20.3 (VSS); also elsewhere on the board
GNDA: C129.2, C130.2, C131.2, C132.2, L2.2; also elsewhere on the board
unnamed: C5.1, D1.2 (A), D2.3 (~~), J12.1
unnamed: C5.2, D2.4 (~~), J13.1, R24.1
unnamed: C6.1, R25.2
unnamed: C6.2, J10.1, R26.2, RL1.4, RL1.5
unnamed: C7.1, C8.1, C135.1, D2.1 (+), U1.1 (VIN)
unnamed: C138.1, R160.1, R161.2, U17.1 (ADJ)
unnamed: C139.1, R162.1, R163.2, U18.1 (ADJ)
unnamed: D1.1 (K), U5.1
unnamed: D15.1 (K), L1.1, U1.2 (OUT)
unnamed: F1.1, F2.1, J6.1
unnamed: F1.2, J8.1
unnamed: F2.2, R25.1, RL1.3, RL1.6, RL2.3, RL2.6
unnamed: J7.1, J9.1, J11.1
unnamed: R24.2, U5.2
unnamed: R26.1, RL2.4, RL2.5
unnamed: R158.2, R159.2, U1.4 (FB)

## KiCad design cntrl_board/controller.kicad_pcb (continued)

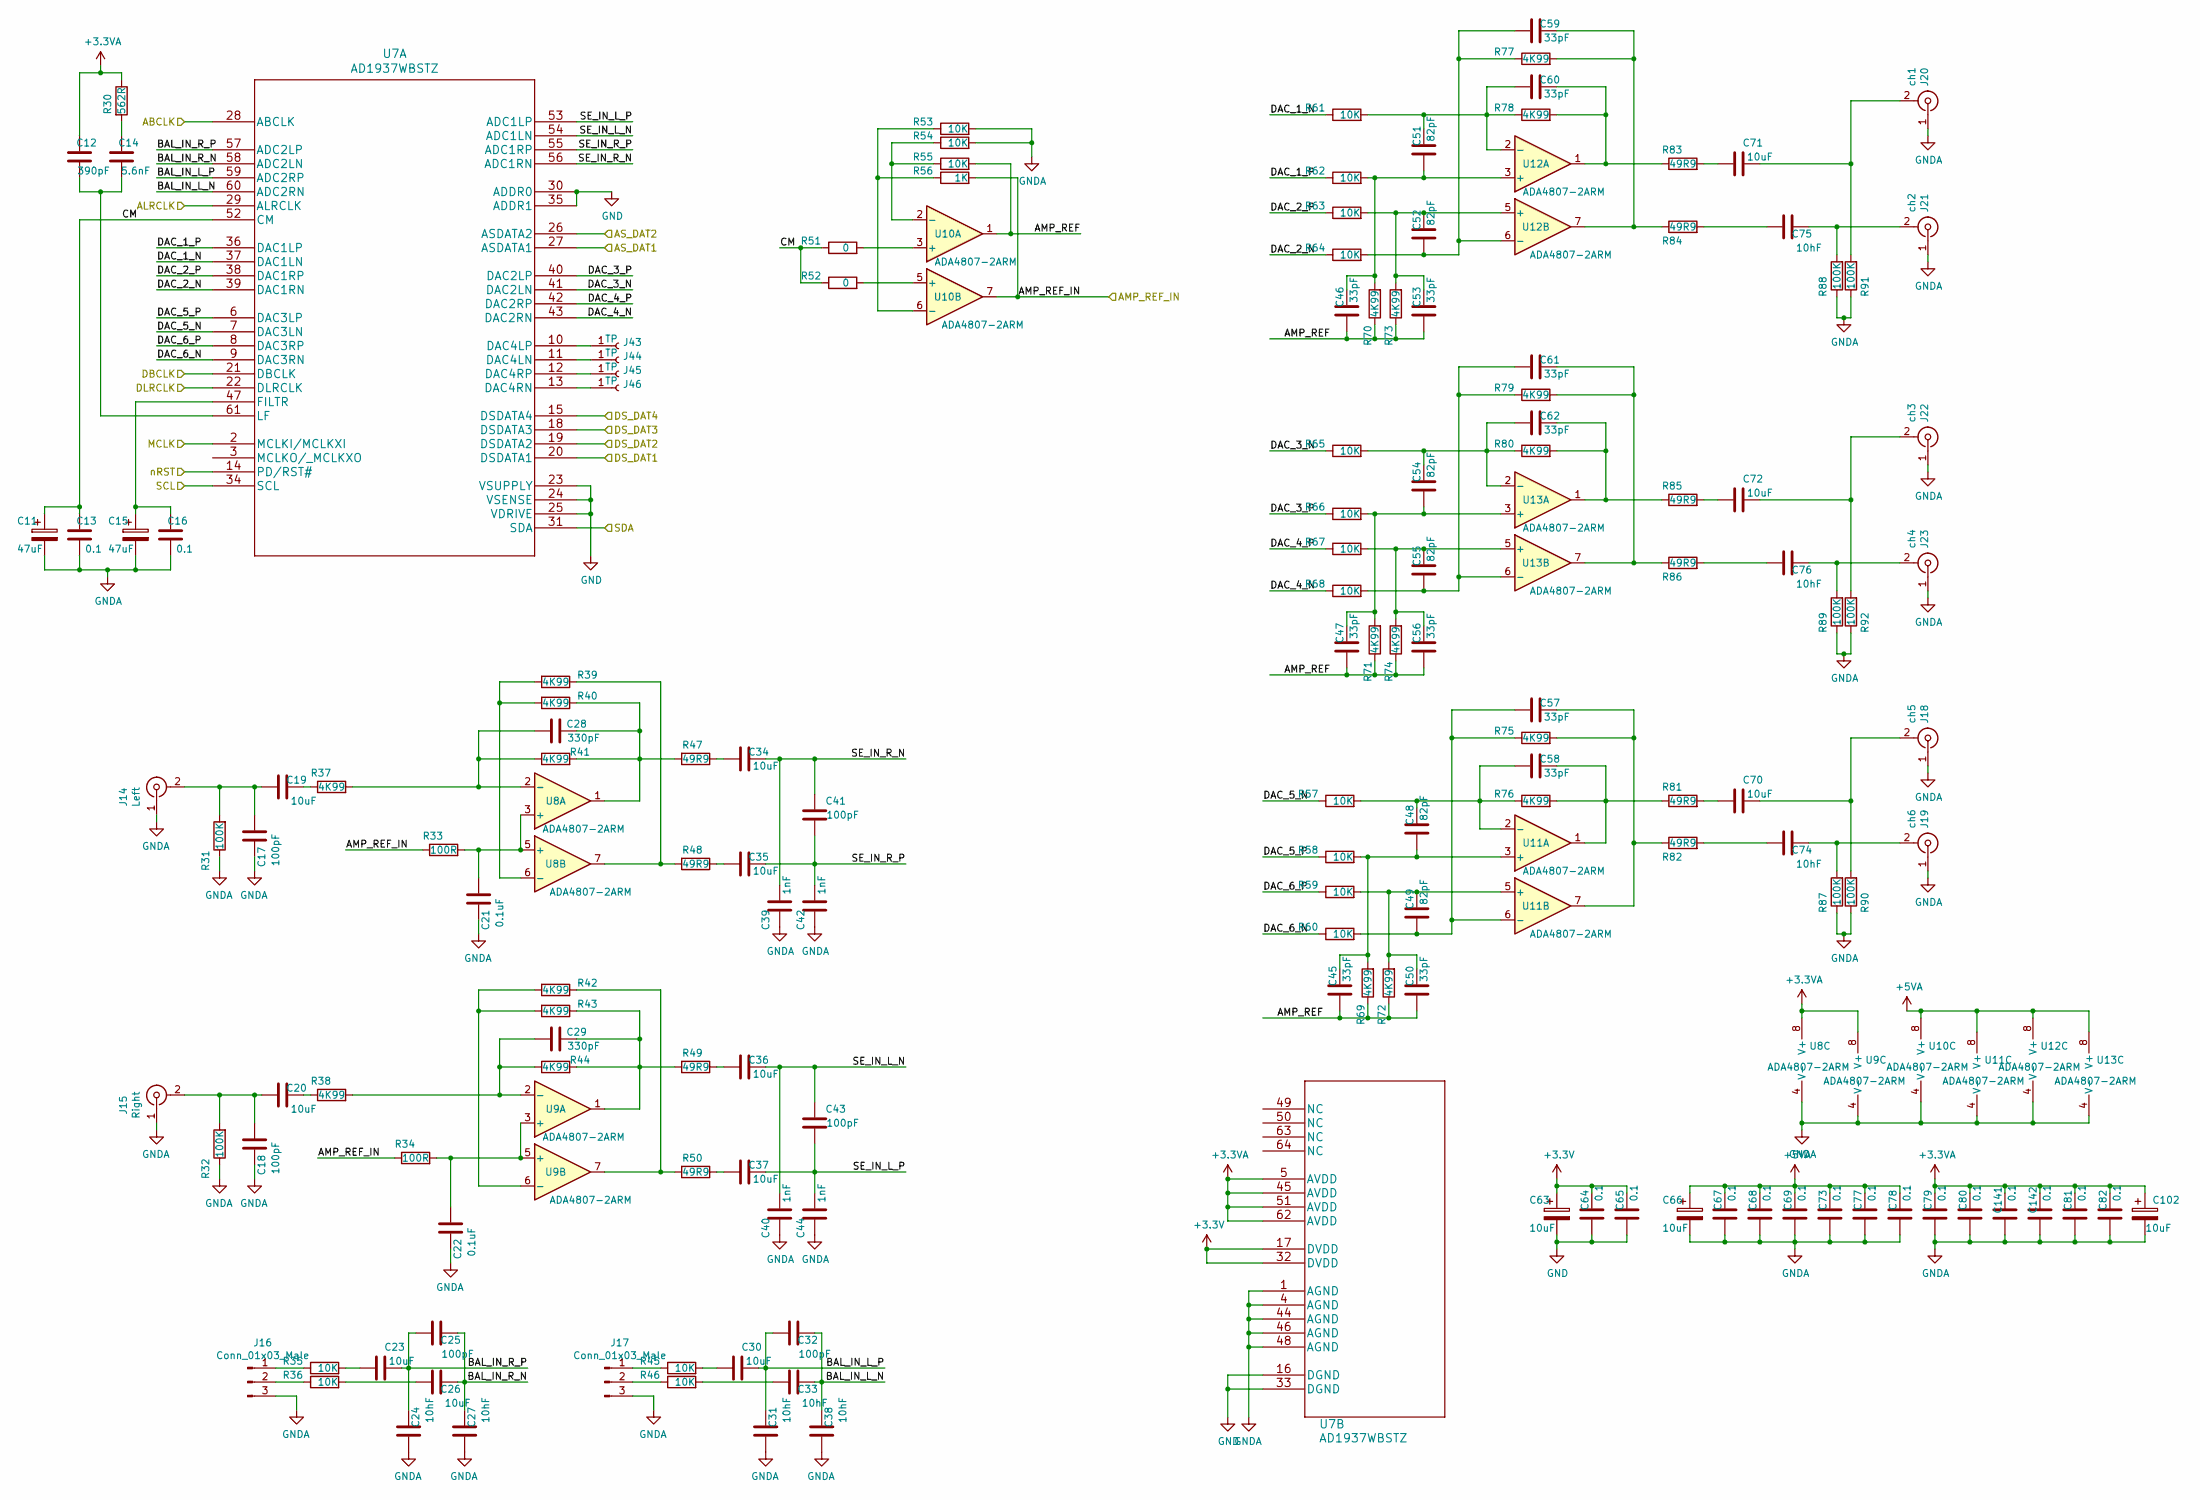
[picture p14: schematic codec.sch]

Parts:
C11, C15: 47uF; CP_Elec_6.3x5.3
C12: 390pF; C_0603_1608Metric_Pad1.08x0.95mm_HandSolder
C13, C16, C64, C65, C67, C68, C69, C73, C77, C78, C79, C80, C81, C82, C141, C142: 0.1; C_0603_1608Metric_Pad1.08x0.95mm_HandSolder
C14: 5.6nF; C_0603_1608Metric_Pad1.08x0.95mm_HandSolder
C17, C18, C25, C32, C41, C43: 100pF; C_0603_1608Metric_Pad1.08x0.95mm_HandSolder
C19, C20, C23, C26, C30, C34, C35, C36, C37, C70, C71, C72: 10uF; C_0805_2012Metric_Pad1.18x1.45mm_HandSolder
C21, C22: 0.1uF; C_0603_1608Metric_Pad1.08x0.95mm_HandSolder
C24, C27, C31, C38: 10hF; C_0603_1608Metric_Pad1.08x0.95mm_HandSolder
C28, C29: 330pF; C_0603_1608Metric_Pad1.08x0.95mm_HandSolder
C33, C74, C75, C76: 10hF; C_0805_2012Metric_Pad1.18x1.45mm_HandSolder
C39, C40, C42, C44: 1nF; C_0603_1608Metric_Pad1.08x0.95mm_HandSolder
C45, C46, C47, C50, C53, C56, C57, C58, C59, C60, C61, C62: 33pF; C_0603_1608Metric_Pad1.08x0.95mm_HandSolder
C48, C49, C51, C52, C54, C55: 82pF; C_0603_1608Metric_Pad1.08x0.95mm_HandSolder
C63, C66, C102: 10uF; CP_Elec_5x5.8
J14: Left; RCJ
J15: Right; RCJ
J16, J17: Conn_01x03_Male; PinHeader_1x03_P2.54mm_Vertical
J18: ch5; RCJ
J19: ch6; RCJ
J20: ch1; RCJ
J21: ch2; RCJ
J22: ch3; RCJ
J23: ch4; RCJ
J43, J44, J45, J46: TP; TestPoint_Keystone_5000-5004_Miniature
R30: 562R; R_0603_1608Metric_Pad0.98x0.95mm_HandSolder
R31, R32, R87, R88, R89, R90, R91, R92: 100K; R_0603_1608Metric_Pad0.98x0.95mm_HandSolder
R33, R34: 100R; R_0603_1608Metric_Pad0.98x0.95mm_HandSolder
R35, R36, R45, R46, R53, R54, R55, R57, R58, R59, R60, R61, R62, R63, R64, R65, R66, R67, R68: 10K; R_0603_1608Metric_Pad0.98x0.95mm_HandSolder
R37, R38, R39, R40, R41, R42, R43, R44, R69, R70, R71, R72, R73, R74, R75, R76, R77, R78, R79, R80: 4K99; R_0603_1608Metric_Pad0.98x0.95mm_HandSolder
R47, R48, R49, R50, R81, R82, R83, R84, R85, R86: 49R9; R_0603_1608Metric_Pad0.98x0.95mm_HandSolder
R51, R52: 0; R_0603_1608Metric_Pad0.98x0.95mm_HandSolder
R56: 1K; R_0603_1608Metric_Pad0.98x0.95mm_HandSolder
U7: AD1937WBSTZ
U8, U9, U10, U11, U12, U13: ADA4807-2ARM; MSOP-8_3x3mm_P0.65mm

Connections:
+3.3VA: C12.1, C79.1, C80.1, C81.1, C82.1, C102.1, C141.1, C142.1, R30.1, U7.5 (AVDD), U7.45 (AVDD), U7.51 (AVDD), U7.62 (AVDD), U8.8 (V+), U9.8 (V+); also elsewhere on the board
+5VA: C66.1, C67.1, C68.1, C69.1, C73.1, C77.1, C78.1, U10.8 (V+), U11.8 (V+), U12.8 (V+), U13.8 (V+); also elsewhere on the board
/codec/ABCLK: U7.28 (ABCLK); also elsewhere on the board
/codec/ALRCLK: U7.29 (ALRCLK); also elsewhere on the board
/codec/AMP_REF: C45.2, C46.2, C47.2, C50.2, C53.2, C56.2, R55.2, R69.1, R70.1, R71.1, R72.1, R73.1, R74.1, U10.1
/codec/AMP_REF_IN: R33.1, R34.1, R56.2, U10.7; also elsewhere on the board
/codec/AS_DAT1: U7.27 (ASDATA1); also elsewhere on the board
/codec/AS_DAT2: U7.26 (ASDATA2); also elsewhere on the board
/codec/BAL_IN_L_N: C32.1, C33.1, C38.1, U7.60 (ADC2RN)
/codec/BAL_IN_L_P: C30.1, C31.1, C32.2, U7.59 (ADC2RP)
/codec/BAL_IN_R_N: C25.1, C26.1, C27.1, U7.58 (ADC2LN)
/codec/BAL_IN_R_P: C23.1, C24.1, C25.2, U7.57 (ADC2LP)
/codec/CM: C11.1, C13.1, R51.1, R52.1, U7.52 (CM)
/codec/DAC_1_N: R61.1, U7.37 (DAC1LN)
/codec/DAC_1_P: R62.1, U7.36 (DAC1LP)
/codec/DAC_2_N: R64.1, U7.39 (DAC1RN)
/codec/DAC_2_P: R63.1, U7.38 (DAC1RP)
/codec/DAC_3_N: R65.1, U7.41 (DAC2LN)
/codec/DAC_3_P: R66.1, U7.40 (DAC2LP)
/codec/DAC_4_N: R68.1, U7.43 (DAC2RN)
/codec/DAC_4_P: R67.1, U7.42 (DAC2RP)
/codec/DAC_5_N: R57.1, U7.7 (DAC3LN)
/codec/DAC_5_P: R58.1, U7.6 (DAC3LP)
/codec/DAC_6_N: R60.1, U7.9 (DAC3RN)
/codec/DAC_6_P: R59.1, U7.8 (DAC3RP)
/codec/DBCLK: U7.21 (DBCLK); also elsewhere on the board
/codec/DLRCLK: U7.22 (DLRCLK); also elsewhere on the board
/codec/DS_DAT1: U7.20 (DSDATA1); also elsewhere on the board
/codec/DS_DAT2: U7.19 (DSDATA2); also elsewhere on the board
/codec/DS_DAT3: U7.18 (DSDATA3); also elsewhere on the board
/codec/DS_DAT4: U7.15 (DSDATA4); also elsewhere on the board
/codec/MCLK: U7.2 (MCLKI/MCLKXI); also elsewhere on the board
/codec/SE_IN_L_N: C36.2, C40.2, C43.2, U7.54 (ADC1LN)
/codec/SE_IN_L_P: C37.2, C43.1, C44.2, U7.53 (ADC1LP)
/codec/SE_IN_R_N: C34.2, C39.2, C41.2, U7.56 (ADC1RN)
/codec/SE_IN_R_P: C35.2, C41.1, C42.2, U7.55 (ADC1RP)
/codec/nRST: U7.14 (PD/RST#); also elsewhere on the board
/ucu/CODEC_SCL: U7.34 (SCL); also elsewhere on the board
/ucu/CODEC_SDA: U7.31 (SDA); also elsewhere on the board
GND: C63.2, C64.2, C65.2, U7.16 (DGND), U7.23 (VSUPPLY), U7.24 (VSENSE), U7.25 (VDRIVE), U7.30 (ADDR0), U7.33 (DGND), U7.35 (ADDR1); also elsewhere on the board
GNDA: C11.2, C13.2, C15.2, C16.2, C17.2, C18.2, C21.2, C22.2, C24.2, C27.2, C31.2, C38.2, C39.1, C40.1, C42.1, C44.1, C66.2, C67.2, C68.2, C69.2, C73.2, C77.2, C78.2, C79.2, C80.2, C81.2, C82.2, C102.2, C141.2, C142.2, J14.1 (In), J15.1 (In), J16.3, J17.3, J18.1 (In), J19.1 (In), J20.1 (In), J21.1 (In), J22.1 (In), J23.1 (In), R31.1, R32.1, R53.2, R54.2, R87.1, R88.1, R89.1, R90.1, R91.1, R92.1, U7.1 (AGND), U7.4 (AGND), U7.44 (AGND), U7.46 (AGND), U7.48 (AGND), U8.4 (V-), U9.4 (V-), U10.4 (V-), U11.4 (V-), U12.4 (V-), U13.4 (V-); also elsewhere on the board
unnamed: C12.2, C14.2, U7.61 (LF)
unnamed: C14.1, R30.2
unnamed: C15.1, C16.1, U7.47 (FILTR)
unnamed: C17.1, C19.2, J14.2 (Ext), R31.2
unnamed: C18.1, C20.2, J15.2 (Ext), R32.2
unnamed: C19.1, R37.1
unnamed: C20.1, R38.1
unnamed: C21.1, R33.2, U8.3 (+), U8.5 (+)
unnamed: C22.1, R34.2, U9.3 (+), U9.5 (+)
unnamed: C23.2, R35.2
unnamed: C26.2, R36.2
unnamed: C28.1, R40.1, R41.2, R47.2, U8.1
unnamed: C28.2, R37.2, R41.1, U8.2 (-)
unnamed: C29.1, R43.1, R44.2, R49.2, U9.1
unnamed: C29.2, R38.2, R44.1, U9.2 (-)
unnamed: C30.2, R45.2
unnamed: C33.2, R46.2
unnamed: C34.1, R47.1
unnamed: C35.1, R48.1
unnamed: C36.1, R49.1
unnamed: C37.1, R50.1
unnamed: C45.1, C48.2, R58.2, R69.2, U11.3 (+)
unnamed: C46.1, C51.2, R62.2, R70.2, U12.3 (+)
unnamed: C47.1, C54.2, R66.2, R71.2, U13.3 (+)
unnamed: C48.1, C58.2, R57.2, R76.1, U11.2 (-)
unnamed: C49.1, C50.1, R59.2, R72.2, U11.5 (+)
unnamed: C49.2, C57.2, R60.2, R75.1, U11.6 (-)
unnamed: C51.1, C60.2, R61.2, R78.1, U12.2 (-)
unnamed: C52.1, C53.1, R63.2, R73.2, U12.5 (+)
unnamed: C52.2, C59.2, R64.2, R77.1, U12.6 (-)
unnamed: C54.1, C62.2, R65.2, R80.1, U13.2 (-)
unnamed: C55.1, C56.1, R67.2, R74.2, U13.5 (+)
unnamed: C55.2, C61.2, R68.2, R79.1, U13.6 (-)
unnamed: C57.1, R75.2, R82.1, U11.7
unnamed: C58.1, R76.2, R81.1, U11.1
unnamed: C59.1, R77.2, R84.1, U12.7
unnamed: C60.1, R78.2, R83.1, U12.1
unnamed: C61.1, R79.2, R86.1, U13.7
unnamed: C62.1, R80.2, R85.1, U13.1
unnamed: C70.1, J18.2 (Ext), R90.2
unnamed: C70.2, R81.2
unnamed: C71.1, J20.2 (Ext), R91.2
unnamed: C71.2, R83.2
unnamed: C72.1, J22.2 (Ext), R92.2
unnamed: C72.2, R85.2
unnamed: C74.1, J19.2 (Ext), R87.2
unnamed: C74.2, R82.2
unnamed: C75.1, J21.2 (Ext), R88.2
unnamed: C75.2, R84.2
unnamed: C76.1, J23.2 (Ext), R89.2
unnamed: C76.2, R86.2
unnamed: J16.1, R35.1
unnamed: J16.2, R36.1
unnamed: J17.1, R45.1
unnamed: J17.2, R46.1
unnamed: J43.1, U7.10 (DAC4LP)
unnamed: J44.1, U7.11 (DAC4LN)
unnamed: J45.1, U7.12 (DAC4RP)
unnamed: J46.1, U7.13 (DAC4RN)
unnamed: R39.1, R48.2, U8.7
unnamed: R39.2, R40.2, U8.6 (-)
unnamed: R42.1, R50.2, U9.7
unnamed: R42.2, R43.2, U9.6 (-)
unnamed: R51.2, U10.3 (+)
unnamed: R52.2, U10.5 (+)
unnamed: R53.1, R56.1, U10.6 (-)
unnamed: R54.1, R55.1, U10.2 (-)

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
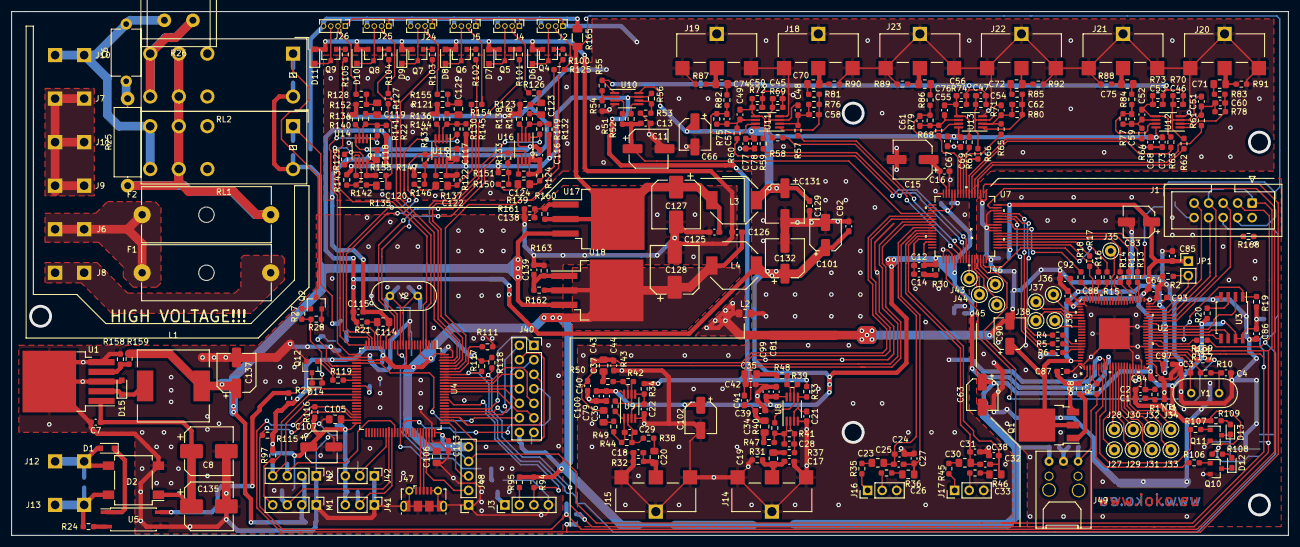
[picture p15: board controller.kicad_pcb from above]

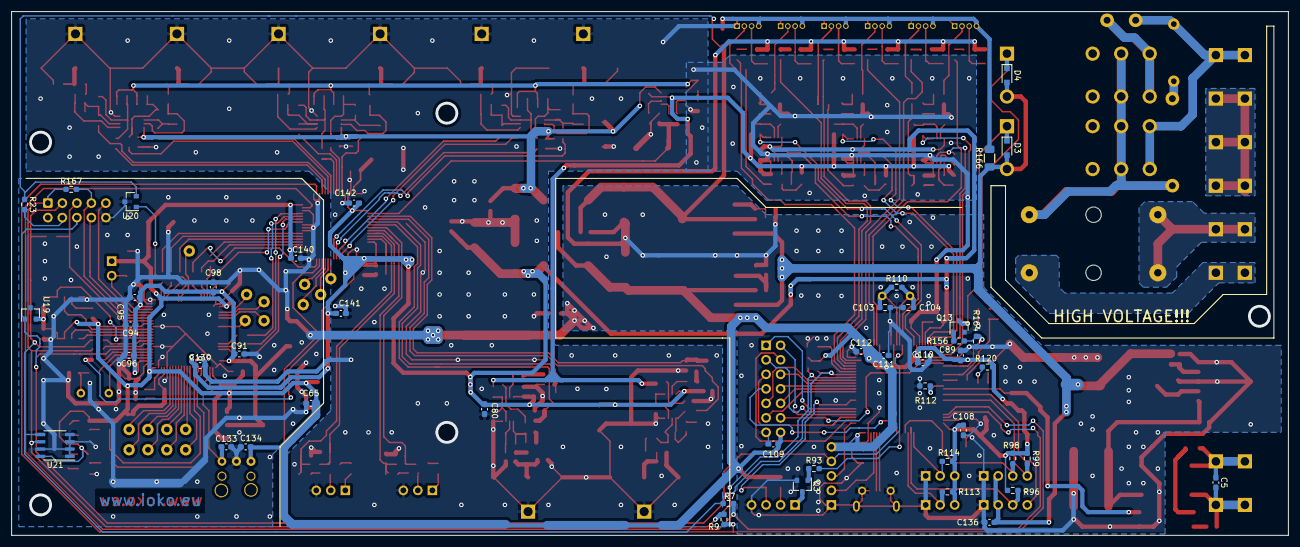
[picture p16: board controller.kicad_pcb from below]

Board: 2 copper layers, 223.5 x 91.7 mm, 420 parts (46 on the bottom side), 285 nets.

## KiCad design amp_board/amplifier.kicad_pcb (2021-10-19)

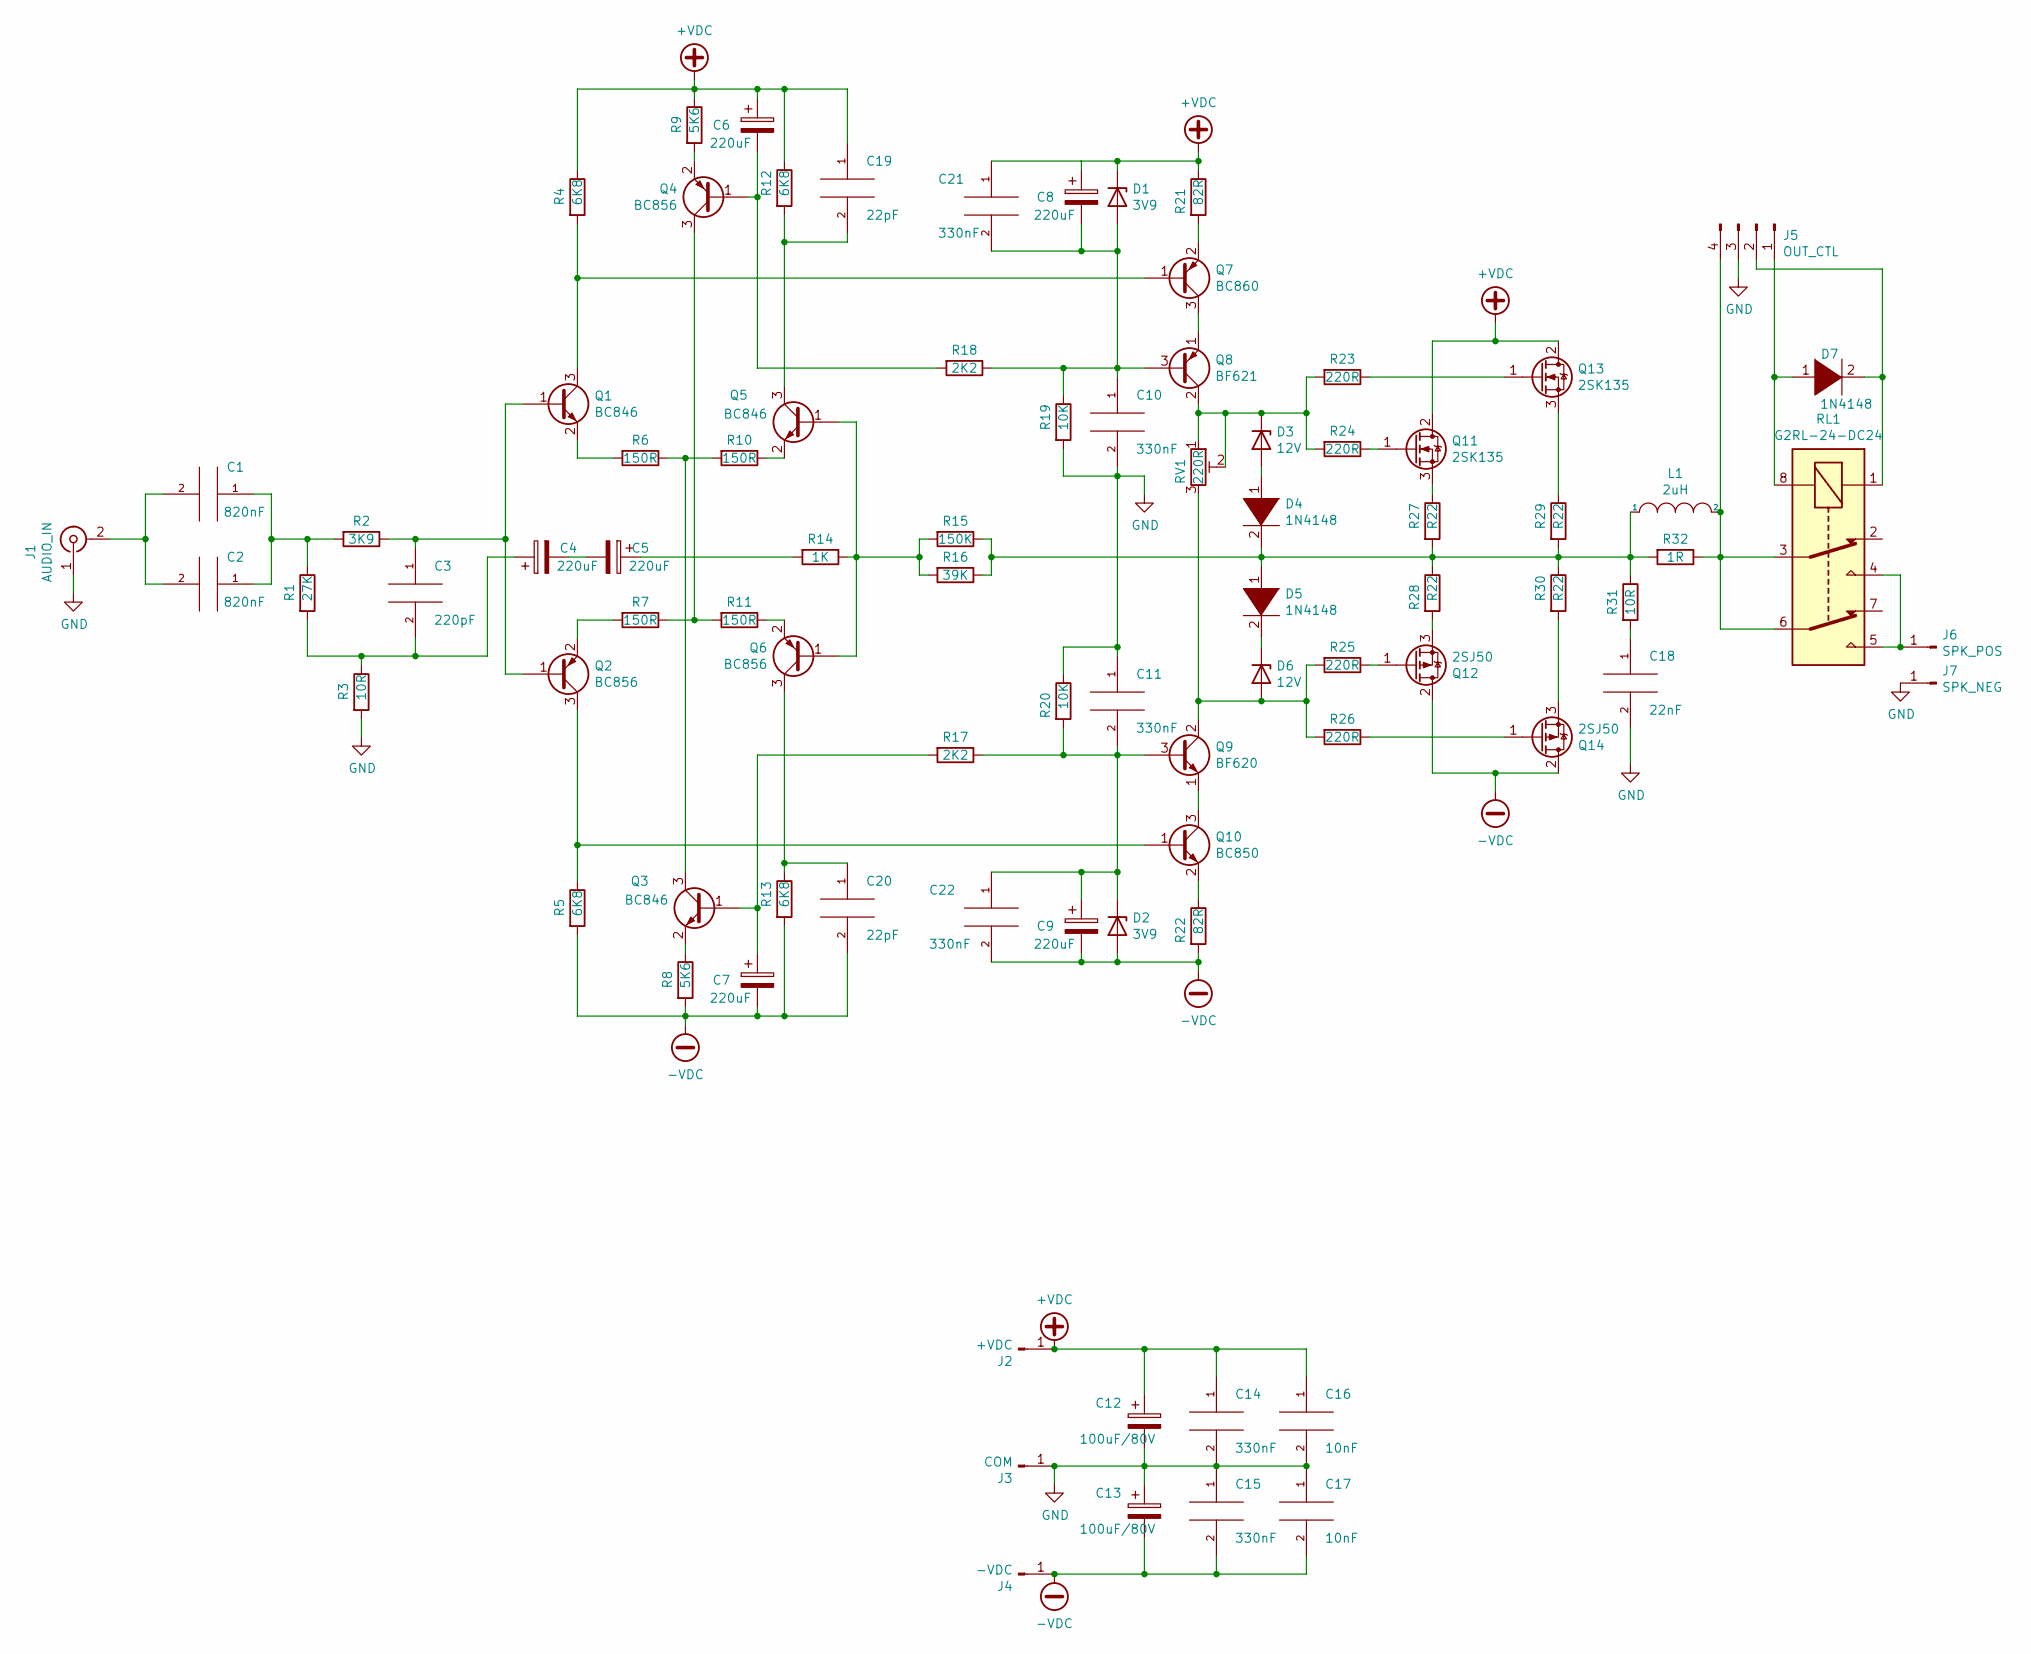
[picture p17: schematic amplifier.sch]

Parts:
C1, C2: 820nF; R_0805_2012Metric_Pad1.20x1.40mm_HandSolder
C3: 220pF; R_0805_2012Metric_Pad1.20x1.40mm_HandSolder
C4, C5, C6, C7, C8, C9: 220uF; CP_Elec_6.3x7.7
C10, C11, C14, C15, C21, C22: 330nF; C_1206_3216Metric_Pad1.33x1.80mm_HandSolder
C12, C13: 100uF/80V; CP_Elec_16x17.5
C16, C17: 10nF; C_0805_2012Metric_Pad1.18x1.45mm_HandSolder
C18: 22nF; C_0805_2012Metric_Pad1.18x1.45mm_HandSolder
C19, C20: 22pF; R_0805_2012Metric_Pad1.20x1.40mm_HandSolder
D1, D2: 3V9; D_SOD-123
D3, D6: 12V; D_SOD-123
D4, D5, D7: 1N4148; D_SOD-323F
J1: AUDIO_IN; RCJ
J2: +VDC; TERMINAL_250
J3: COM; TERMINAL_250
J4: -VDC; TERMINAL_250
J5: OUT_CTL; PinHeader_1x04_P1.27mm_Vertical
J6: SPK_POS; TERMINAL_250
J7: SPK_NEG; TERMINAL_250
L1: 2uH; R_Axial_Power_L38.0mm_W9.0mm_P40.64mm
Q1, Q3, Q5: BC846; SOT-23
Q2, Q4, Q6: BC856; SOT-23
Q7: BC860; SOT-23
Q8: BF621; SOT-89-3_Handsoldering
Q9: BF620; SOT-89-3_Handsoldering
Q10: BC850; SOT-23
Q11, Q13: 2SK135; TO-3
Q12, Q14: 2SJ50; TO-3
R1: 27K; R_0603_1608Metric_Pad0.98x0.95mm_HandSolder
R2: 3K9; R_0603_1608Metric_Pad0.98x0.95mm_HandSolder
R3: 10R; R_0603_1608Metric_Pad0.98x0.95mm_HandSolder
R4, R5, R12, R13: 6K8; R_0603_1608Metric_Pad0.98x0.95mm_HandSolder
R6, R7, R10, R11: 150R; R_0603_1608Metric_Pad0.98x0.95mm_HandSolder
R8, R9: 5K6; R_0603_1608Metric_Pad0.98x0.95mm_HandSolder
R14: 1K; R_0603_1608Metric_Pad0.98x0.95mm_HandSolder
R15: 150K; R_0603_1608Metric_Pad0.98x0.95mm_HandSolder
R16: 39K; R_0603_1608Metric_Pad0.98x0.95mm_HandSolder
R17, R18: 2K2; R_0603_1608Metric_Pad0.98x0.95mm_HandSolder
R19, R20: 10K; R_2512_6332Metric_Pad1.40x3.35mm_HandSolder
R21, R22: 82R; R_2512_6332Metric_Pad1.40x3.35mm_HandSolder
R23, R24, R25, R26: 220R; R_0603_1608Metric_Pad0.98x0.95mm_HandSolder
R27, R28, R29, R30: R22; R_Axial_Power_L38.0mm_W9.0mm_P40.64mm
R31: 10R; R_2512_6332Metric_Pad1.40x3.35mm_HandSolder
R32: 1R; R_2512_6332Metric_Pad1.40x3.35mm_HandSolder
RL1: G2RL-24-DC24; Relay_DPDT_Omron_G2RL
RV1: 220R; Potentiometer_Bourns_3296Y_Vertical

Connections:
+VDC: C6.1, C8.1, C12.1, C14.1, C16.1, C19.1, C21.1, D1.1 (K), J2.1, Q11.2 (D), Q13.2 (D), R4.1, R9.1, R12.1, R21.1
-VDC: C7.2, C9.2, C13.2, C15.2, C17.2, C20.2, C22.2, D2.2 (A), J4.1, Q12.2 (D), Q14.2 (D), R5.2, R8.2, R13.2, R22.2
GND: C10.2, C11.1, C12.2, C13.1, C14.2, C15.1, C16.2, C17.1, C18.2, J1.1 (In), J3.1, J5.3, J7.1, R3.2, R19.2, R20.1
unnamed: C1.1, C2.1, R1.1, R2.2
unnamed: C1.2, C2.2, J1.2 (Ext)
unnamed: C3.1, Q1.1 (B), Q2.1 (B), R2.1
unnamed: C3.2, C4.1, R1.2, R3.1
unnamed: C4.2, C5.2
unnamed: C5.1, R14.2
unnamed: C6.2, Q4.1 (B), R18.2
unnamed: C7.1, Q3.1 (B), R17.2
unnamed: C8.2, C10.1, C21.2, D1.2 (A), Q8.3 (B), R18.1, R19.1
unnamed: C9.1, C11.2, C22.1, D2.1 (K), Q9.3 (B), R17.1, R20.2
unnamed: C18.1, R31.2
unnamed: C19.2, Q5.3 (C), R12.2
unnamed: C20.1, Q6.3 (C), R13.1
unnamed: D3.1 (K), Q8.2 (C), R23.2, R24.2, RV1.1, RV1.2
unnamed: D3.2 (A), D4.1 (K)
unnamed: D4.2 (A), D5.1 (K), L1.1, R15.1, R16.1, R27.2, R28.1, R29.2, R30.1, R31.1, R32.2
unnamed: D5.2 (A), D6.1 (K)
unnamed: D6.2 (A), Q9.2 (C), R25.2, R26.2, RV1.3
unnamed: D7.1 (K), J5.1, RL1.8
unnamed: D7.2 (A), J5.2, RL1.1
unnamed: J5.4, L1.2, R32.1, RL1.3, RL1.6
unnamed: J6.1, RL1.4, RL1.5
unnamed: Q1.2 (E), R6.2
unnamed: Q1.3 (C), Q7.1 (B), R4.2
unnamed: Q2.2 (E), R7.2
unnamed: Q3.2 (E), R8.1
unnamed: Q3.3 (C), R6.1, R10.2
unnamed: Q4.2 (E), R9.2
unnamed: Q4.3 (C), R7.1, R11.2
unnamed: Q5.1 (B), Q6.1 (B), R14.1, R15.2, R16.2
unnamed: Q5.2 (E), R10.1
unnamed: Q6.2 (E), R11.1
unnamed: Q7.2 (E), R21.2
unnamed: Q7.3 (C), Q8.1 (E)
unnamed: Q2.3 (C), Q10.1 (B), R5.1
unnamed: Q10.2 (E), R22.1
unnamed: Q9.1 (E), Q10.3 (C)
unnamed: Q11.1 (G), R24.1
unnamed: Q11.3 (S), R27.1
unnamed: Q12.1 (G), R25.1
unnamed: Q12.3 (S), R28.2
unnamed: Q13.1 (G), R23.1
unnamed: Q13.3 (S), R29.1
unnamed: Q14.1 (G), R26.1
unnamed: Q14.3 (S), R30.2

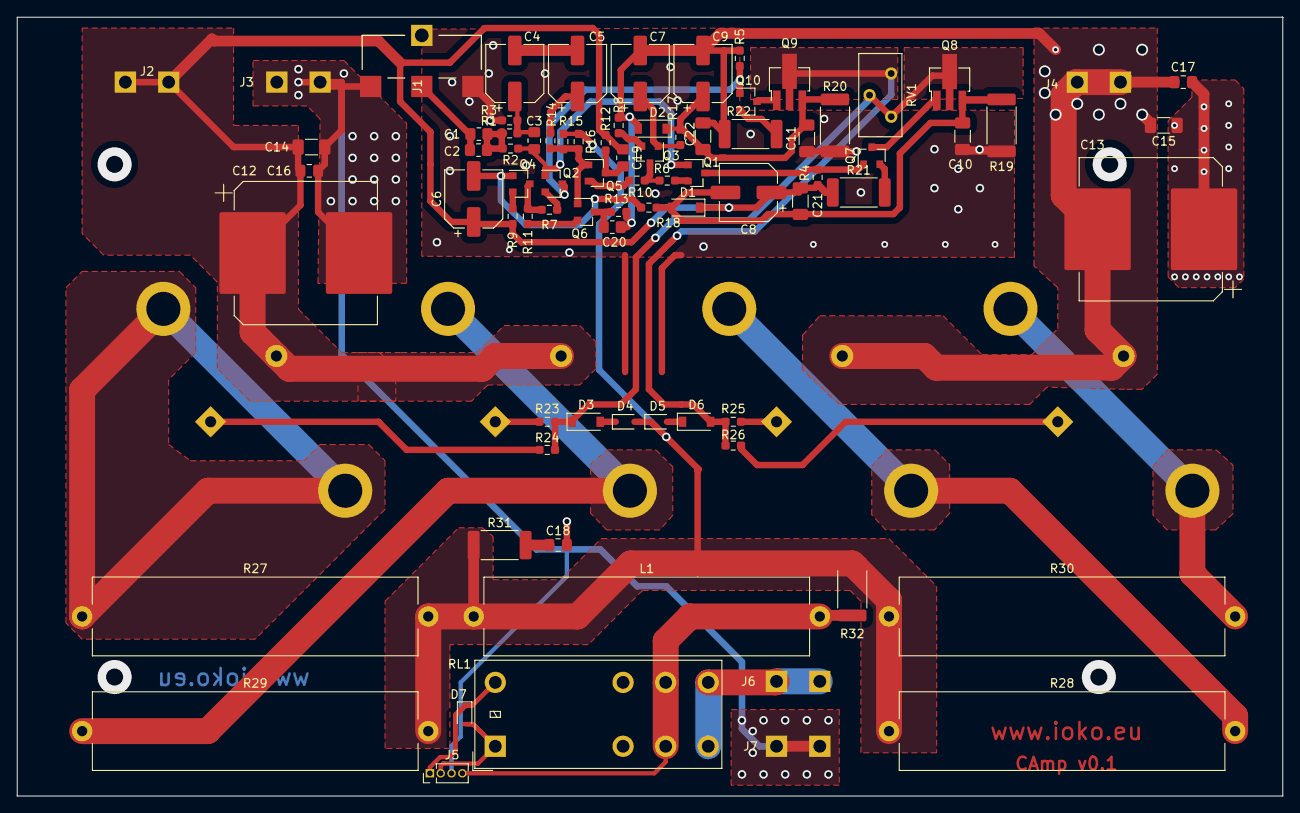
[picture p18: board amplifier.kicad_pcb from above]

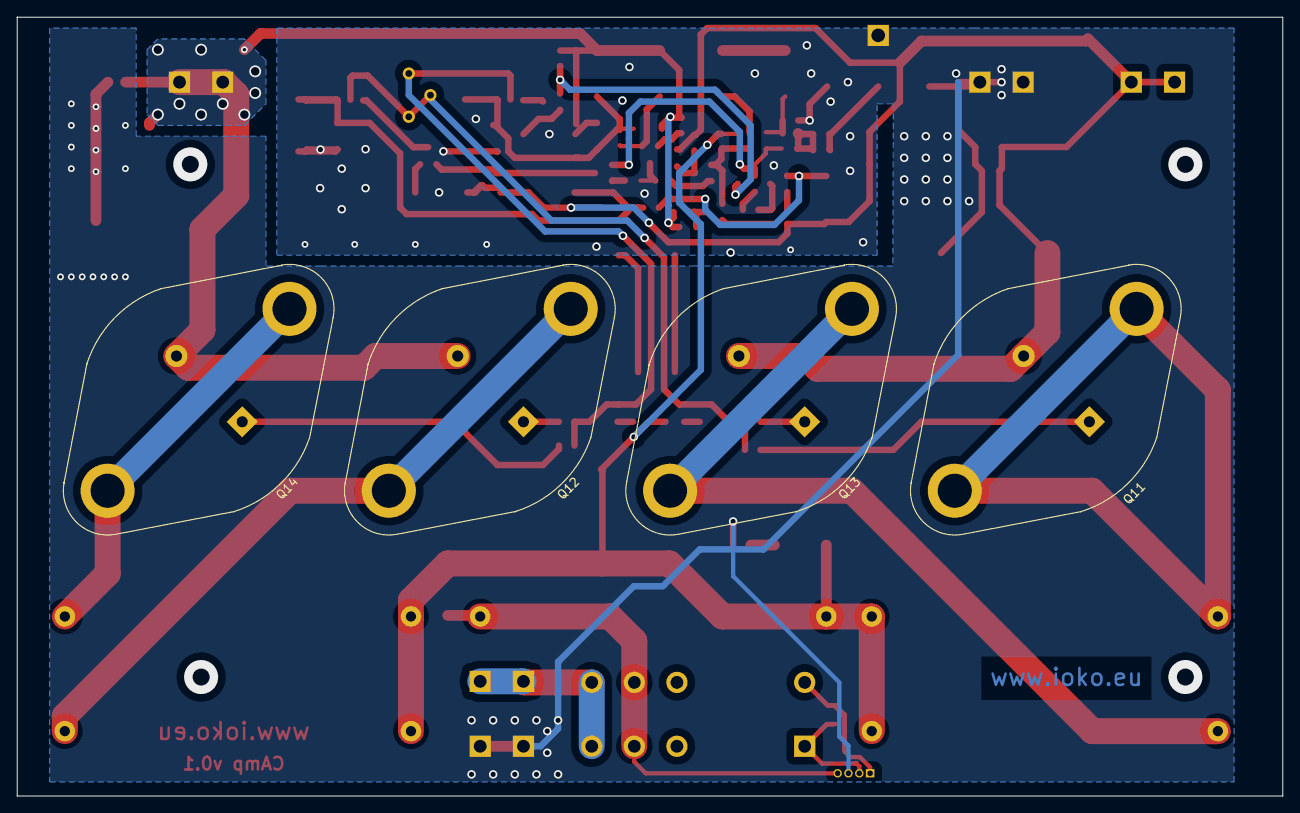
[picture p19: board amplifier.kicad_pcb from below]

Board: 2 copper layers, 148.6 x 91.4 mm, 85 parts (4 on the bottom side), 48 nets.

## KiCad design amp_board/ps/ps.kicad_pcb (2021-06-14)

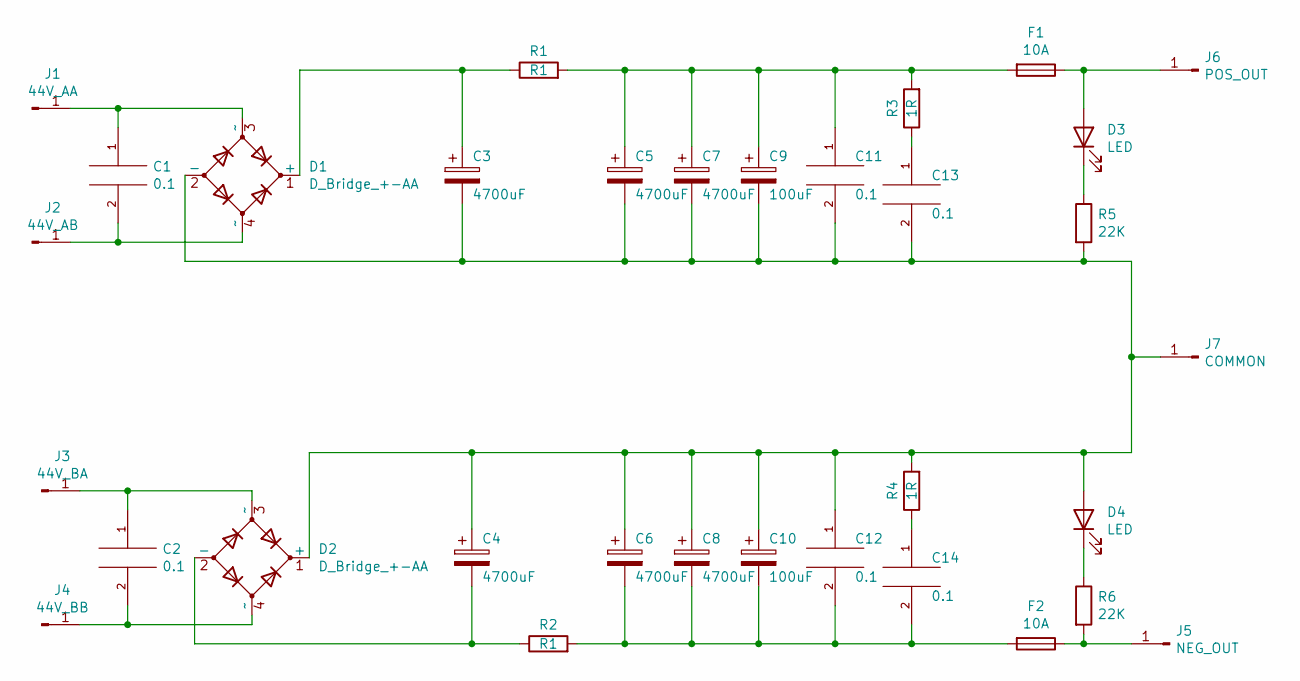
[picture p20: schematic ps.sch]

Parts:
C1, C2, C11, C12, C13, C14: 0.1; C_0805_2012Metric_Pad1.18x1.45mm_HandSolder
C3, C4, C5, C6, C7, C8: 4700uF; CP_Radial_D26.0mm_P12.00mm_SnapIn
C9, C10: 100uF; CP_Axial_L10.0mm_D4.5mm_P15.00mm_Horizontal
D1, D2: D_Bridge_+-AA; BRIDGE
D3, D4: LED; LED_0603_1608Metric_Pad1.05x0.95mm_HandSolder
F1, F2: 10A; Fuseholder_Cylinder-5x20mm_Stelvio-Kontek_PTF78_Horizontal_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
J1: 44V_AA; TERMINAL_250
J2: 44V_AB; TERMINAL_250
J3: 44V_BA; TERMINAL_250
J4: 44V_BB; TERMINAL_250
J5: NEG_OUT; TERMINAL_250
J6: POS_OUT; TERMINAL_250
J7: COMMON; TERMINAL_250
R1, R2: R1; R_Axial_Power_L25.0mm_W9.0mm_P30.48mm
R3, R4: 1R; R_2512_6332Metric_Pad1.40x3.35mm_HandSolder
R5, R6: 22K; R_0603_1608Metric_Pad0.98x0.95mm_HandSolder

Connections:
unnamed: C1.1, D1.3 (~~), J1.1
unnamed: C1.2, D1.4 (~~), J2.1
unnamed: C2.1, D2.3 (~~), J3.1
unnamed: C2.2, D2.4 (~~), J4.1
unnamed: C3.1, D1.1 (+), R1.1
unnamed: C4.2, D2.2 (-), R2.1
unnamed: C3.2, C4.1, C5.2, C6.1, C7.2, C8.1, C9.2, C10.1, C11.2, C12.1, C13.2, D1.2 (-), D2.1 (+), D4.2 (A), J7.1, R4.2, R5.2
unnamed: C6.2, C8.2, C10.2, C12.2, C14.2, F2.2, R2.2
unnamed: C5.1, C7.1, C9.1, C11.1, F1.2, R1.2, R3.2
unnamed: C13.1, R3.1
unnamed: C14.1, R4.1
unnamed: D3.1 (K), R5.1
unnamed: D3.2 (A), F1.1, J6.1
unnamed: D4.1 (K), R6.1
unnamed: F2.1, J5.1, R6.2

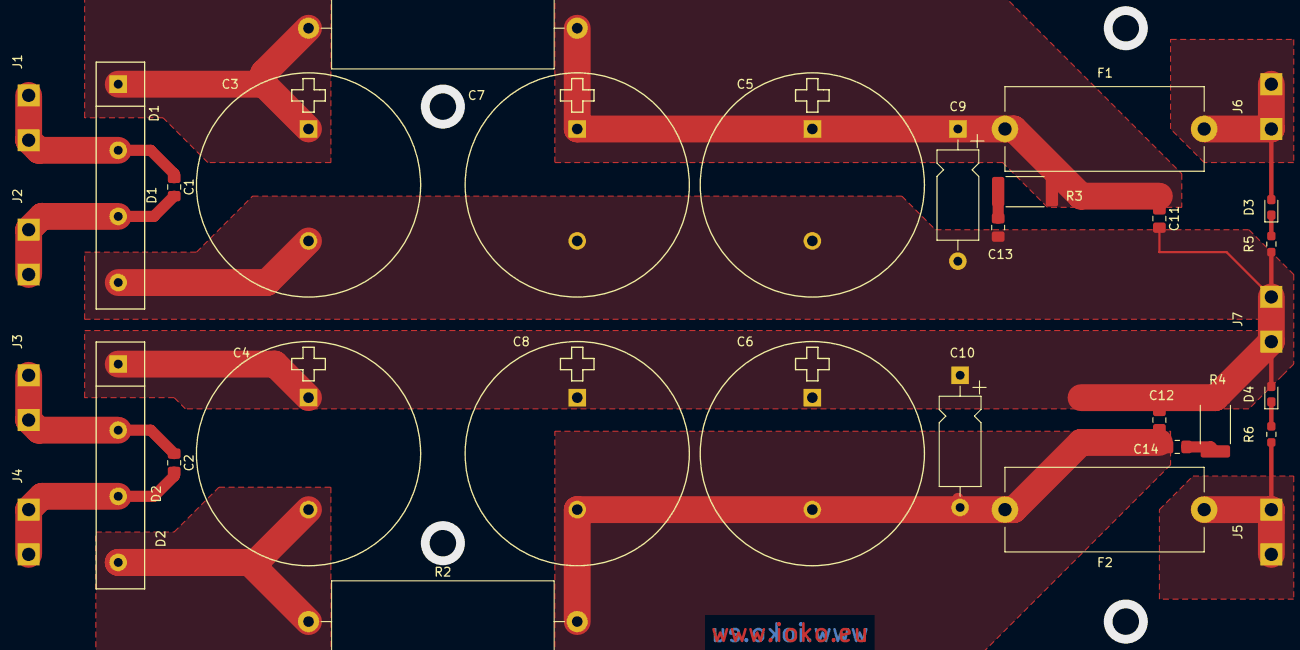
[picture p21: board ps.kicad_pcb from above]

Board: 2 copper layers, 33 parts (0 on the bottom side), 15 nets.

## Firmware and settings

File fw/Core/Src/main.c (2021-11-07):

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
/* Includes ------------------------------------------------------------------*/
#include "main.h"
#include "cmsis_os.h"

/* USER CODE BEGIN PD */
extern uint8_t touch_pending;
extern uint8_t state;
I2C_HandleTypeDef hi2c2;
static void MX_I2C2_Init(void);
/* USER CODE END PD */

I2C_HandleTypeDef hi2c1;

RTC_HandleTypeDef hrtc;

SPI_HandleTypeDef hspi1;
SPI_HandleTypeDef hspi3;
DMA_HandleTypeDef hdma_spi1_tx;

TIM_HandleTypeDef htim1;
TIM_HandleTypeDef htim3;
TIM_HandleTypeDef htim4;
TIM_HandleTypeDef htim5;

/* Definitions for idleTask */
osThreadId_t idleTaskHandle;
const osThreadAttr_t idleTask_attributes = {
  .name = "idleTask",
  .stack_size = 128 * 4,
  .priority = (osPriority_t) osPriorityNormal,
};
/* Definitions for buttonTask */
osThreadId_t buttonTaskHandle;
const osThreadAttr_t buttonTask_attributes = {
  .name = "buttonTask",
  .stack_size = 512 * 4,
  .priority = (osPriority_t) osPriorityNormal,
};
/* Definitions for fanTask */
osThreadId_t fanTaskHandle;
const osThreadAttr_t fanTask_attributes = {
  .name = "fanTask",
  .stack_size = 512 * 4,
  .priority = (osPriority_t) osPriorityNormal,
};
/* Definitions for displayTask */
osThreadId_t displayTaskHandle;
const osThreadAttr_t displayTask_attributes = {
  .name = "displayTask",
  .stack_size = 512 * 4,
  .priority = (osPriority_t) osPriorityNormal,
};
/* Definitions for touchTask */
osThreadId_t touchTaskHandle;
const osThreadAttr_t touchTask_attributes = {
  .name = "touchTask",
  .stack_size = 128 * 4,
  .priority = (osPriority_t) osPriorityNormal,
};
/* Definitions for dspTask */
osThreadId_t dspTaskHandle;
const osThreadAttr_t dspTask_attributes = {
  .name = "dspTask",
  .stack_size = 128 * 4,
  .priority = (osPriority_t) osPriorityNormal,
};
/* Definitions for sensorATask */
osThreadId_t sensorATaskHandle;
const osThreadAttr_t sensorATask_attributes = {
  .name = "sensorATask",
  .stack_size = 128 * 4,
  .priority = (osPriority_t) osPriorityNormal,
};
/* Definitions for displayQueue */
osMessageQueueId_t displayQueueHandle;
const osMessageQueueAttr_t displayQueue_attributes = {
  .name = "displayQueue"
};
/* Definitions for fanQueue */
osMessageQueueId_t fanQueueHandle;
const osMessageQueueAttr_t fanQueue_attributes = {
  .name = "fanQueue"
};
void SystemClock_Config(void);
static void MX_GPIO_Init(void);
static void MX_DMA_Init(void);
static void MX_RTC_Init(void);
static void MX_SPI1_Init(void);
static void MX_SPI3_Init(void);
static void MX_TIM1_Init(void);
static void MX_TIM3_Init(void);
static void MX_TIM4_Init(void);
static void MX_TIM5_Init(void);
static void MX_I2C1_Init(void);
void idleTaskEntry(void *argument);
extern void buttonTaskEntry(void *argument);
extern void fanTaskEntry(void *argument);
extern void displayTaskEntry(void *argument);
extern void touchTaskEntry(void *argument);
extern void dspTaskEntry(void *argument);
extern void sensorATaskEntry(void *argument);

/**
  * @brief  The application entry point.
  * @retval int
  */
int main(void)
{
  /* MCU Configuration--------------------------------------------------------*/

  /* Reset of all peripherals, Initializes the Flash interface and the Systick. */
  HAL_Init();

  /* Configure the system clock */
  SystemClock_Config();

  /* Initialize all configured peripherals */
  MX_GPIO_Init();
  MX_DMA_Init();
  MX_RTC_Init();
  MX_SPI1_Init();
  MX_SPI3_Init();
  MX_TIM1_Init();
  MX_TIM3_Init();
  MX_TIM4_Init();
  MX_TIM5_Init();
  MX_I2C1_Init();
  /* USER CODE BEGIN 2 */
  //MX_I2C2_Init();
  /* USER CODE END 2 */

  /* Init scheduler */
  osKernelInitialize();

  /* USER CODE BEGIN RTOS_MUTEX */
  /* add mutexes, ... */
  /* USER CODE END RTOS_MUTEX */

  /* USER CODE BEGIN RTOS_SEMAPHORES */
  /* add semaphores, ... */
  /* USER CODE END RTOS_SEMAPHORES */

  /* USER CODE BEGIN RTOS_TIMERS */
  /* start timers, add new ones, ... */
  /* USER CODE END RTOS_TIMERS */

  /* Create the queue(s) */
  /* creation of displayQueue */
  displayQueueHandle = osMessageQueueNew (16, sizeof(uint16_t), &displayQueue_attributes);

  /* creation of fanQueue */
  fanQueueHandle = osMessageQueueNew (16, sizeof(uint16_t), &fanQueue_attributes);

  /* USER CODE BEGIN RTOS_QUEUES */
  /* add queues, ... */
  /* USER CODE END RTOS_QUEUES */

  /* Create the thread(s) */
  /* creation of idleTask */
  idleTaskHandle = osThreadNew(idleTaskEntry, NULL, &idleTask_attributes);

  /* creation of buttonTask */
  buttonTaskHandle = osThreadNew(buttonTaskEntry, NULL, &buttonTask_attributes);

  /* creation of fanTask */
  fanTaskHandle = osThreadNew(fanTaskEntry, NULL, &fanTask_attributes);

  /* creation of displayTask */
  displayTaskHandle = osThreadNew(displayTaskEntry, NULL, &displayTask_attributes);

  /* creation of touchTask */
  touchTaskHandle = osThreadNew(touchTaskEntry, NULL, &touchTask_attributes);

  /* creation of dspTask */
  dspTaskHandle = osThreadNew(dspTaskEntry, NULL, &dspTask_attributes);

  /* creation of sensorATask */
  sensorATaskHandle = osThreadNew(sensorATaskEntry, NULL, &sensorATask_attributes);

  /* USER CODE BEGIN RTOS_THREADS */
  /* add threads, ... */
  /* USER CODE END RTOS_THREADS */

  /* USER CODE BEGIN RTOS_EVENTS */
  /* add events, ... */
  /* USER CODE END RTOS_EVENTS */

  /* Start scheduler */
  osKernelStart();

  /* We should never get here as control is now taken by the scheduler */
  /* Infinite loop */
  /* USER CODE BEGIN WHILE */
  while (1)
  {
    /* USER CODE END WHILE */

    /* USER CODE BEGIN 3 */
  }
  /* USER CODE END 3 */
}

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
/* USER CODE BEGIN 4 */
void HAL_GPIO_EXTI_Callback(uint16_t GPIO_Pin)
{
	if (TOUCH_IRQ_Pin & GPIO_Pin) {
	  touch_pending = 1;
	}
	if (AC_IN_Pin & GPIO_Pin) {
	  if (state == SS_REQUEST) {
		HAL_GPIO_WritePin(AC_RES_GPIO_Port, AC_RES_Pin, GPIO_PIN_SET);
	    state++;
	  }
	  if (state == XFR_ON) {
		HAL_GPIO_WritePin(AC_CTRL_GPIO_Port, AC_CTRL_Pin, GPIO_PIN_SET);
		HAL_GPIO_WritePin(AC_RES_GPIO_Port, AC_RES_Pin, GPIO_PIN_RESET);
	    state++;
	  }
	  if (state == SB_REQUEST) {
		HAL_GPIO_WritePin(AC_CTRL_GPIO_Port, AC_CTRL_Pin, GPIO_PIN_RESET);
		HAL_GPIO_WritePin(AC_RES_GPIO_Port, AC_RES_Pin, GPIO_PIN_RESET);
	    state++;
	  }
	}
}

static void MX_I2C2_Init(void)
{

  hi2c2.Instance = I2C2;
  hi2c2.Init.ClockSpeed = 100000;
  hi2c2.Init.DutyCycle = I2C_DUTYCYCLE_2;
  hi2c2.Init.OwnAddress1 = 0;
  hi2c2.Init.AddressingMode = I2C_ADDRESSINGMODE_7BIT;
  hi2c2.Init.DualAddressMode = I2C_DUALADDRESS_DISABLE;
  hi2c2.Init.OwnAddress2 = 0;
  hi2c2.Init.GeneralCallMode = I2C_GENERALCALL_DISABLE;
  hi2c2.Init.NoStretchMode = I2C_NOSTRETCH_DISABLE;
  if (HAL_I2C_Init(&hi2c2) != HAL_OK)
  {
    Error_Handler();
  }
}
/* USER CODE END 4 */

/* USER CODE BEGIN Header_idleTaskEntry */
/**
  * @brief  Function implementing the idleTask thread.
  * @param  argument: Not used
  * @retval None
  */
/* USER CODE END Header_idleTaskEntry */
void idleTaskEntry(void *argument)
{
  /* USER CODE BEGIN 5 */
  /* Infinite loop */
  for(;;)
  {
    // Status LED blinking
    HAL_GPIO_WritePin(LED_GPIO_Port, LED_Pin, GPIO_PIN_SET);
    osDelay(100);
    HAL_GPIO_WritePin(LED_GPIO_Port, LED_Pin, GPIO_PIN_RESET);
	osDelay(100);
  }
  /* USER CODE END 5 */
}

/**
  * @brief  Period elapsed callback in non blocking mode
  * @note   This function is called  when TIM10 interrupt took place, inside
  * HAL_TIM_IRQHandler(). It makes a direct call to HAL_IncTick() to increment
  * a global variable "uwTick" used as application time base.
  * @param  htim : TIM handle
  * @retval None
  */
void HAL_TIM_PeriodElapsedCallback(TIM_HandleTypeDef *htim)
{
  if (htim->Instance == TIM10) {
    HAL_IncTick();
  }
}

/**
  * @brief  This function is executed in case of error occurrence.
  * @retval None
  */
void Error_Handler(void)
{
  /* USER CODE BEGIN Error_Handler_Debug */
  /* User can add his own implementation to report the HAL error return state */
  __disable_irq();
  while (1)
  {
  }
  /* USER CODE END Error_Handler_Debug */
}

#ifdef  USE_FULL_ASSERT
/**
  * @brief  Reports the name of the source file and the source line number
  *         where the assert_param error has occurred.
  * @param  file: pointer to the source file name
  * @param  line: assert_param error line source number
  * @retval None
  */
void assert_failed(uint8_t *file, uint32_t line)
{
  /* USER CODE BEGIN 6 */
  /* User can add his own implementation to report the file name and line number,
     ex: printf("Wrong parameters value: file %s on line %d\r\n", file, line) */
  /* USER CODE END 6 */
}
#endif /* USE_FULL_ASSERT */

/************************ (C) COPYRIGHT STMicroelectronics *****END OF FILE****/

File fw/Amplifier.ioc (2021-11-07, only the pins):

Mcu.UserName=STM32F407VETx
PA13.Signal=SYS_JTMS-SWDIO
PA14.Signal=SYS_JTCK-SWCLK
PA15.GPIO_Label=TOUCH_nCS
PA15.Signal=SPI3_NSS
PA4.GPIO_Label=LCD_CS
PA4.Signal=GPIO_Output
PA5.GPIO_Label=AC_CTRL
PA5.Signal=GPIO_Output
PB0.GPIO_Label=LED
PB0.Signal=GPIO_Output
PB10.Signal=GPIO_Output
PB11.Signal=GPIO_Output
PB3.Signal=SPI1_SCK
PB4.Signal=SPI1_MISO
PB5.Signal=SPI1_MOSI
PB6.Signal=I2C1_SCL
PB7.Signal=I2C1_SDA
PB8.GPIO_Label=CH1_OUT
PB8.Signal=GPIO_Output
PB9.GPIO_Label=CH2_OUT
PB9.Signal=GPIO_Output
PC10.GPIO_Label=TOUCH_SCK
PC10.Signal=SPI3_SCK
PC11.GPIO_Label=TOUCH_MISO
PC11.Signal=SPI3_MISO
PC12.GPIO_Label=TOUCH_MOSI
PC12.Signal=SPI3_MOSI
PC2.GPIO_Label=CH5
PC2.Signal=ADCx_IN12
PC3.GPIO_Label=CH6
PC3.Signal=ADCx_IN13
PC4.GPIO_Label=AC_RES
PC4.Signal=GPIO_Output
PC6.GPIO_Label=BUT_LED
PC6.Signal=S_TIM3_CH1
PC7.GPIO_Label=LCD_BL
PC7.Signal=S_TIM3_CH2
PD0.GPIO_Label=TOUCH_IRQ
PD0.Signal=GPXTI0
PD11.GPIO_Label=TS2
PD11.Signal=GPIO_Input
PD12.GPIO_Label=FAN1_IN
PD12.Signal=S_TIM4_CH1
PD13.GPIO_Label=TS1
PD13.Signal=GPIO_Input
PD14.GPIO_Label=FAN2_IN
PD14.Signal=S_TIM4_CH3
PD3.GPIO_Label=PON
PD3.Signal=GPIO_Input
PD6.GPIO_Label=LCD_RST
PD6.Signal=GPIO_Output
PD7.GPIO_Label=LCD_DC
PD7.Signal=GPIO_Output
PE0.GPIO_Label=CH3_OUT
PE0.Signal=GPIO_Output
PE1.GPIO_Label=CH4_OUT
PE1.Signal=GPIO_Output
PE11.GPIO_Label=FAN2_CTRL
PE11.Signal=S_TIM1_CH2
PE2.Signal=SYS_TRACECLK
PE3.Signal=SYS_TRACED0
PE4.Signal=SYS_TRACED1
PE5.GPIO_Label=CH5_OUT
PE5.Signal=GPIO_Output
PE6.GPIO_Label=CH6_OUT
PE6.Signal=GPIO_Output
PE7.GPIO_Label=AC_IN
PE7.Signal=GPXTI7
PE9.GPIO_Label=FAN1_CTRL
PE9.Signal=S_TIM1_CH1
PH0-OSC_IN.Signal=RCC_OSC_IN
PH1-OSC_OUT.Signal=RCC_OSC_OUT

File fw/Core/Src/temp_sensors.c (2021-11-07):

#include "stm32f4xx_hal.h"
#include "cmsis_os.h"
#include "cmsis_os2.h"
#include "main.h"

extern osMessageQueueId_t displayQueueHandle;
extern osMessageQueueId_t fanQueueHandle;
extern TIM_HandleTypeDef htim5;

// Left sensor
#define	DS18B20_L_PORT 	TS1_GPIO_Port
#define	DS18B20_L_PIN 	TS1_Pin

// Right sensor
#define	DS18B20_R_PORT 	TS2_GPIO_Port
#define	DS18B20_R_PIN 	TS2_Pin

// Set GPIO as output
void set_gpio_output(uint32_t pin) {
	GPIO_InitTypeDef GPIO_InitStruct = {0};

	GPIO_InitStruct.Pin = pin;
	GPIO_InitStruct.Mode = GPIO_MODE_OUTPUT_PP;
	GPIO_InitStruct.Pull = GPIO_NOPULL;
	GPIO_InitStruct.Speed = GPIO_SPEED_FREQ_VERY_HIGH;
	HAL_GPIO_Init(GPIOD, &GPIO_InitStruct);
}

// Set GPIO as input
void set_gpio_intput(uint32_t pin) {
	GPIO_InitTypeDef GPIO_InitStruct = {0};

	GPIO_InitStruct.Pin = pin;
	GPIO_InitStruct.Mode = GPIO_MODE_INPUT;
	GPIO_InitStruct.Pull = GPIO_PULLUP;
	GPIO_InitStruct.Speed = GPIO_SPEED_FREQ_VERY_HIGH;
	HAL_GPIO_Init(GPIOD, &GPIO_InitStruct);
}

// timer based dealy - in usec
void ds_delay (uint32_t us) {
    __HAL_TIM_SET_COUNTER(&htim5,0);
    while ((__HAL_TIM_GET_COUNTER(&htim5))<us);
}

uint8_t ds_crc8(const unsigned char * data, const uint32_t size)
{
    uint8_t crc = 0;
    for (uint32_t i = 0; i < size; ++i)
    {
        uint8_t inbyte = data[i];
        for (uint8_t j = 0; j < 8; ++j) {
        	uint8_t mix = (crc ^ inbyte) & 0x01;
            crc >>= 1;
            if (mix) crc ^= 0x8C;
            inbyte >>= 1;
        }
    }
    return crc;
}

// send start command
uint8_t DS18B20_Start(uint32_t pin) {
	uint8_t Response = 0;
	set_gpio_output(pin);
	HAL_GPIO_WritePin (GPIOD, pin, 0);
	ds_delay(500);

	set_gpio_intput(pin);
	ds_delay(80);

	if (!(HAL_GPIO_ReadPin(GPIOD, pin))) Response = 1;
	else Response = -1;
	ds_delay(400);

	return Response;
}

// write to the device
void DS18B20_Write(uint32_t pin, uint8_t data) {
	set_gpio_output(pin);

	for (int i=0; i<8; i++)	{
		if ((data & (1<<i))!=0) {
			set_gpio_output(pin);
			HAL_GPIO_WritePin (GPIOD, pin, 0);
			ds_delay(1);
			set_gpio_intput(pin);
			ds_delay(50);
		} else {
			set_gpio_output(pin);
			HAL_GPIO_WritePin (GPIOD, pin, 0);
			ds_delay(50);
			set_gpio_intput(pin);
		}
	}
}

// read from the device
uint8_t DS18B20_Read(uint32_t pin) {
	uint8_t value=0;
	set_gpio_intput(pin);

	for (int i=0;i<8;i++) {
		set_gpio_output(pin);

		HAL_GPIO_WritePin (GPIOD, pin, 0);
		ds_delay(2);

		set_gpio_intput(pin);
		if (HAL_GPIO_ReadPin (GPIOD, pin)) {
			value |= 1<<i;
		}
		ds_delay(60);
	}
	return value;
}


void sensorATaskEntry(void const * argument) {
	uint16_t display_event;
	uint8_t buffer[9];
	int32_t i;

	for(;;) {
		HAL_TIM_Base_Start(&htim5);
		DS18B20_Start(DS18B20_L_PIN);
		HAL_Delay(1);
		DS18B20_Write(DS18B20_L_PIN, 0xCC);  // skip ROM
		DS18B20_Write(DS18B20_L_PIN, 0x44);  // convert t
		HAL_Delay (800);

		DS18B20_Start(DS18B20_L_PIN);
		HAL_Delay(1);
		DS18B20_Write(DS18B20_L_PIN, 0xCC);  // skip ROM
		DS18B20_Write(DS18B20_L_PIN, 0xBE);  // Read Scratch-pad

		for (i = 0; i < 9 ; i++) {
		    buffer[i] = DS18B20_Read(DS18B20_L_PIN);
		}

        //Check CRC
//		if (ds_crc8(&buffer, 7) == buffer[8]) {
			// send data
			display_event = 10*(((buffer[0] & 0xF0) >> 4) + ((buffer[1] & 0x07) << 4));
			display_event = display_event + (10 * (buffer[0] & 0x0F)) / 16;
			display_event |= 0x2000;
//			if (buffer[1] > 0x07) {
//				display_event |= 0x1000;
//			}
			osMessageQueuePut(displayQueueHandle, &display_event, 10, 0);
			osMessageQueuePut(fanQueueHandle, &display_event, 10, 0);

//		}

		osDelay(2000);
	}
}

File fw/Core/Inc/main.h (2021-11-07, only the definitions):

#define CODEC_ADD  0x04   //!< AD1937 I2C address
#define DSP_ADD    0x76   //!< ADAU1467 I2C address
#define MEM_ADD    0xA0   //!< I2C EEPROM address
#define CH5_OUT_Pin GPIO_PIN_5
#define CH5_OUT_GPIO_Port GPIOE
#define CH6_OUT_Pin GPIO_PIN_6
#define CH6_OUT_GPIO_Port GPIOE
#define CH5_Pin GPIO_PIN_2
#define CH5_GPIO_Port GPIOC
#define CH6_Pin GPIO_PIN_3
#define CH6_GPIO_Port GPIOC
#define LCD_CS_Pin GPIO_PIN_4
#define LCD_CS_GPIO_Port GPIOA
#define AC_CTRL_Pin GPIO_PIN_5
#define AC_CTRL_GPIO_Port GPIOA
#define AC_RES_Pin GPIO_PIN_4
#define AC_RES_GPIO_Port GPIOC
#define LED_Pin GPIO_PIN_0
#define LED_GPIO_Port GPIOB
#define AC_IN_Pin GPIO_PIN_7
#define AC_IN_GPIO_Port GPIOE
#define AC_IN_EXTI_IRQn EXTI9_5_IRQn
#define FAN1_CTRL_Pin GPIO_PIN_9
#define FAN1_CTRL_GPIO_Port GPIOE
#define FAN2_CTRL_Pin GPIO_PIN_11
#define FAN2_CTRL_GPIO_Port GPIOE
#define TS2_Pin GPIO_PIN_11
#define TS2_GPIO_Port GPIOD
#define FAN1_IN_Pin GPIO_PIN_12
#define FAN1_IN_GPIO_Port GPIOD
#define TS1_Pin GPIO_PIN_13
#define TS1_GPIO_Port GPIOD
#define FAN2_IN_Pin GPIO_PIN_14
#define FAN2_IN_GPIO_Port GPIOD
#define BUT_LED_Pin GPIO_PIN_6
#define BUT_LED_GPIO_Port GPIOC
#define LCD_BL_Pin GPIO_PIN_7
#define LCD_BL_GPIO_Port GPIOC
#define TOUCH_nCS_Pin GPIO_PIN_15
#define TOUCH_nCS_GPIO_Port GPIOA
#define TOUCH_SCK_Pin GPIO_PIN_10
#define TOUCH_SCK_GPIO_Port GPIOC
#define TOUCH_MISO_Pin GPIO_PIN_11
#define TOUCH_MISO_GPIO_Port GPIOC
#define TOUCH_MOSI_Pin GPIO_PIN_12
#define TOUCH_MOSI_GPIO_Port GPIOC
#define TOUCH_IRQ_Pin GPIO_PIN_0
#define TOUCH_IRQ_GPIO_Port GPIOD
#define PON_Pin GPIO_PIN_3
#define PON_GPIO_Port GPIOD
#define LCD_RST_Pin GPIO_PIN_6
#define LCD_RST_GPIO_Port GPIOD
#define LCD_DC_Pin GPIO_PIN_7
#define LCD_DC_GPIO_Port GPIOD
#define CH1_OUT_Pin GPIO_PIN_8
#define CH1_OUT_GPIO_Port GPIOB
#define CH2_OUT_Pin GPIO_PIN_9
#define CH2_OUT_GPIO_Port GPIOB
#define CH3_OUT_Pin GPIO_PIN_0
#define CH3_OUT_GPIO_Port GPIOE
#define CH4_OUT_Pin GPIO_PIN_1
#define CH4_OUT_GPIO_Port GPIOE

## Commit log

2021-07-05 update components
    [amplifier.kicad_pcb, codec.sch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]
2021-09-18 Fix misc issues
    [controller.kicad_pcb, dsp.sch, ps.sch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]
2021-09-19 fw added
    [amplifier-B_Cu.gbl, amplifier-B_Mask.gbs, amplifier-B_Paste.gbp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]
2021-10-19 update xformer soft startup
    [amplifier.kicad_pcb, amplifier.sch, codec.sch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]
2021-10-22 add 3d print models
    [cable_spacer.FCStd, cable_spacer.stl, fuse.FCStd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]
2021-11-07 fix CPU-DSP channel
    [controller.kicad_pcb, dsp.sch]

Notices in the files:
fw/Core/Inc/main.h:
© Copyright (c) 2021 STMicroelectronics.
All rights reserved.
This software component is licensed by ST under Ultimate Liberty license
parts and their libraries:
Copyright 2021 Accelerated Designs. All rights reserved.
